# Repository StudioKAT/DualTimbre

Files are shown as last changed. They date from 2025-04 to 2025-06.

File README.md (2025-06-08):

# Dual Timbre
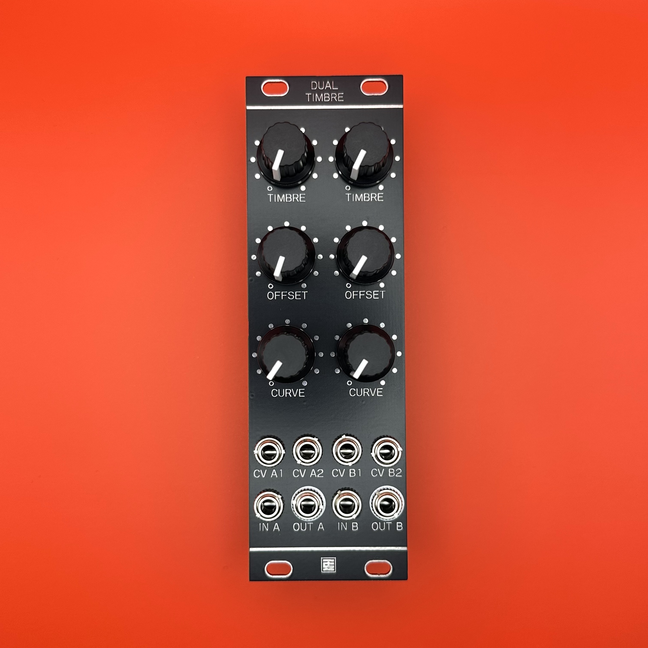
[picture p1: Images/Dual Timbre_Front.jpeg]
Dual Timbre Front


## 概要 / Overview

**Dual Timbre** は、Buchlaのウェーブフォルダー回路を現代的にアレンジした、デュアル構成のサウンドシェイピングツールです。  
VCAのレスポンスカーブは、リニアからエクスポネンシャルまで連続的に調整可能です。  
TIMBREおよびOFFSETノブは、パッチケーブルが接続されていない場合にはVCAの開き具合を調整するコントロールとして機能し、CV信号が接続されている場合にはアッテネーターとして動作します。  
CV入力は0～+10V、オーディオ入力は±5V（10Vpp）を想定しています。  

**Dual Timbre** is a dual-channel sound shaping tool that offers a modern take on the Buchla wavefolder circuit.  
The VCA response curve is continuously adjustable from linear to exponential.  
The TIMBRE and OFFSET knobs act as controls for the VCA's opening amount when no patch cable is connected, and serve as attenuators when a CV signal is present.  
The CV input expects a 0 to +10V signal, while the audio input is designed for ±5V (10V peak-to-peak).  

## 仕様 / Spec
- Format: Eurorack
- Function: Buchla Style Wave Folder
- Current needs: +12V: 55mA, -12V: 55mA
- Width: 8 HP
- Depth: 35mm (including power connector)

## 動画 / Movie
Dual Timbre (https://youtu.be/piGdNXMZIGw)

v1.1 UPDATE  
https://x.com/StudioKAT_synth/status/1931323608674316583

## 販売 / Sales

StudioKATオフィシャルショップで販売しています。(日本国内限定)  
 https://www.studiokat.jp/items/109037903

## ライセンス / License

この作品は [Creative Commons 表示 - 継承 4.0 国際 (CC BY-SA 4.0)](https://creativecommons.org/licenses/by-sa/4.0/deed.ja) の下でライセンスされています。  
This work is licensed under the [Creative Commons Attribution-ShareAlike 4.0 International License](https://creativecommons.org/licenses/by-sa/4.0/).

## クレジット / Credits

- Designed by : StudioKAT
- Website : https://www.studiokat.jp/
- GitHub : https://github.com/StudioKAT
- X(Twitter) : https://x.com/StudioKAT_synth
- Instagram : https://www.instagram.com/studiokat_modular/

## 更新履歴 / Changelog

- `2025-05-28` v1.0 Release
- `2025-06-08` v1.1 Curveの向き変更

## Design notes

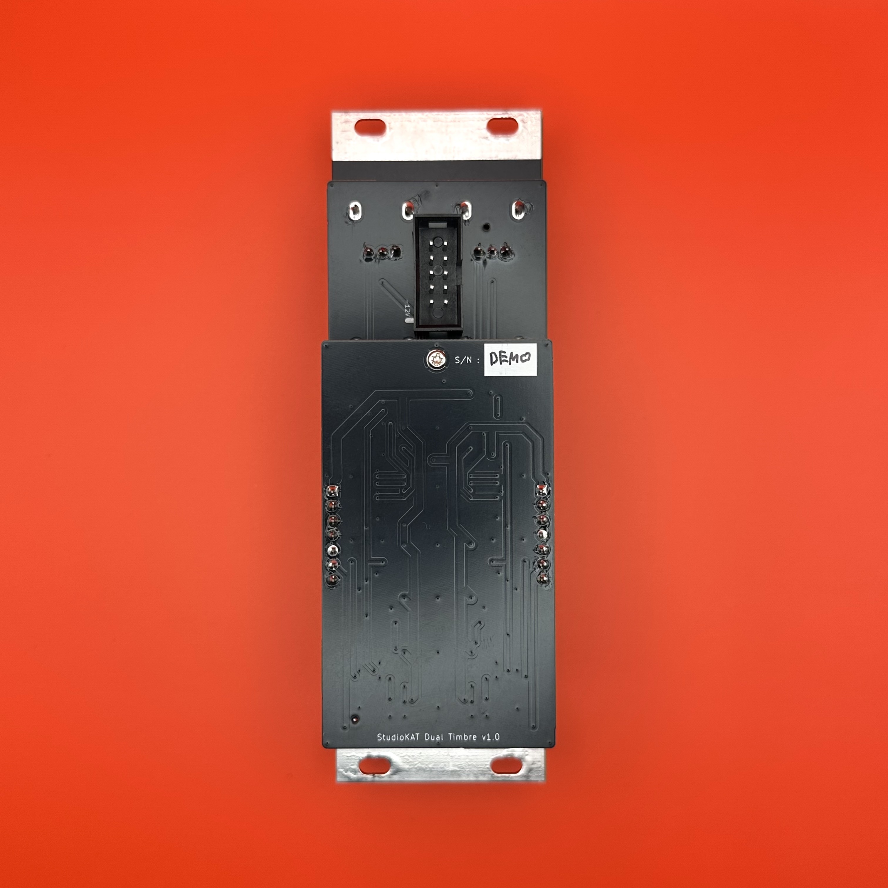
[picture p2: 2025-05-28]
Images/Dual Timbre_Back.jpeg

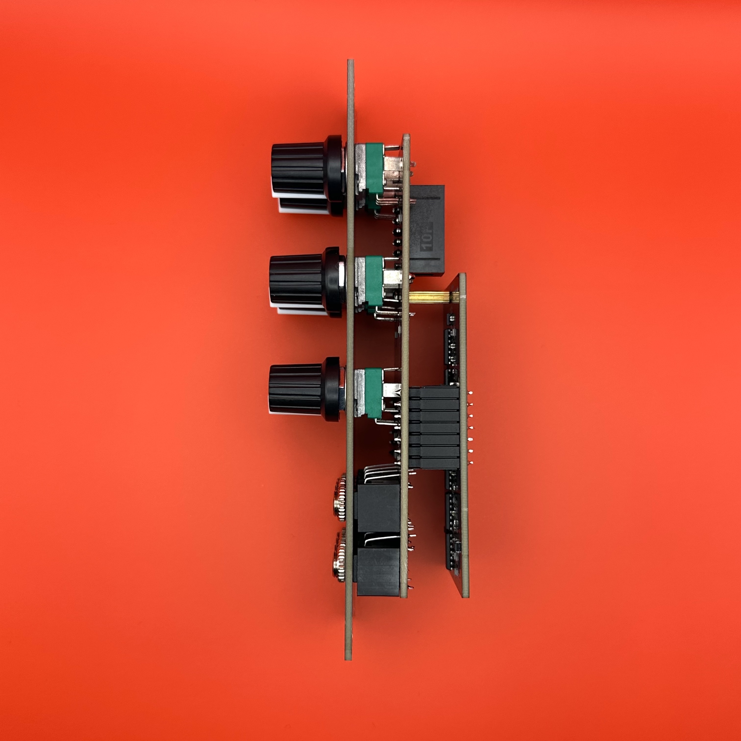
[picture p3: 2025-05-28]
Images/Dual Timbre_Side.jpeg

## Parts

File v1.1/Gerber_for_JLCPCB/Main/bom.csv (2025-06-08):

Designator | Footprint | Quantity | Value | LCSC Part #
C1, C2 | 0603 | 2 | 100nF | C14663
C10, C11, C12, C13, C14, C15, C16, C17, C18, C3, C6, C7, C8, C9 | 0402 | 14 | 100nF | C1525
C19, C20, C23, C24 | 0805 | 4 | 2.2nF | C28260
C21, C22, C25, C26 | 0402 | 4 | 100pF | C1546
C27, C28 | 0402 | 2 | 47pF | C1567
C4, C5 | 0805 | 2 | 22uF | C45783
D1, D2 | D_SOD-323 | 2 | 1N5819WS | C64886
D3, D4, D5, D6 | D_SOD-323 | 4 | 1N4148WS | C2128
J1 | BoxHeader_2x05_2.54mm_Europower | 1 | POWER
J10 | AudioJack_PJ301M-12 | 1 | Offset_CV_2
J11 | AudioJack_PJ301M-12 | 1 | Audio_IN_2
J12 | AudioJack_PJ301M-12 | 1 | TIMBRE_OUT_1
J13 | AudioJack_PJ301M-12 | 1 | TIMBRE_OUT_2
J2, J3 | PinSocket_1x07_P2.54mm_Vertical | 2 | Conn_01x07_Socket
J4, J5 | PinHeader_1x07_P2.54mm_Vertical | 2 | Conn_01x07_Pin
J6 | AudioJack_PJ301M-12 | 1 | Timbre_CV_1
J7 | AudioJack_PJ301M-12 | 1 | Offset_CV_1
J8 | AudioJack_PJ301M-12 | 1 | Audio_IN_1
J9 | AudioJack_PJ301M-12 | 1 | Timbre_CV_2
R1, R48, R72 | 0402 | 3 | 1K | C11702
R10, R21 | 0402 | 2 | 20K | C25765
R11, R19, R22, R8 | 0402 | 4 | 120R | C25079
R12, R23 | 0603 | 2 | 2K | C22975
R13, R24 | 0603 | 2 | 15K | C22809
R14, R16, R3, R5 | 0603 | 4 | 24K | C23352
R15, R17, R4, R6 | 0603 | 4 | 120K | C25808
R18, R7 | 0603 | 2 | 43K | C23172
R2 | 0402 | 1 | 510K | C11616
R20, R9 | 0402 | 2 | 10M | C26082
R25, R49 | 0402 | 2 | 10K | C25744
R26, R43, R45, R50, R67, R69 | 0402 | 6 | 51K | C25794
R27, R51 | 0603 | 2 | 91K | C23265
R28, R52 | 0603 | 2 | 30K | C22984
R29, R53 | 0402 | 2 | 68K | C36871
R30, R31, R32, R33, R34, R44, R54, R55, R56, R57, R58, R68 | 0402 | 12 | 150K | C25755
R35, R59 | 0402 | 2 | 100K | C25741
R36, R60 | 0402 | 2 | 47K | C25792
R37, R61 | 0402 | 2 | 470K | C25790
R38, R62 | 0402 | 2 | 18K | C25762
R39, R63 | 0402 | 2 | 75K | C25798
R40, R64 | 0603 | 2 | 1.5M | C4172
R41, R65 | 0402 | 2 | 33K | C25779
R42, R66 | 0603 | 2 | 240K | C4197
R46, R70 | 0603 | 2 | 22K | C31850
R47, R71 | 0603 | 2 | 470K | C23178
RV1, RV2, RV3, RV4, RV5, RV6 | Potentiometer_RV09 | 6 | B10K
U1 | SOT-23 | 1 | CJ431 | C3113
U2, U3, U4, U5, U6 | SOIC-14_3.9x8.7mm_P1.27mm | 5 | TL074 | C6963
U7 | SOIC-16_3.9x9.9mm_P1.27mm | 1 | SSI2164

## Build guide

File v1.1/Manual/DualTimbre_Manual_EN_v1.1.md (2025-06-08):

# Dual Timbre Manual (EN)

Dual Timbre Front

## Overview

**Dual Timbre** is a dual-channel sound shaping tool that offers a modern take on the Buchla wavefolder circuit.  
The VCA response curve is continuously adjustable from linear to exponential.  
The TIMBRE and OFFSET knobs act as controls for the VCA’s opening amount when no patch cable is connected, and serve as attenuators when a CV signal is connected.  
The CV inputs are designed for 0 to +10V signals, and the audio inputs for ±5V (10V peak-to-peak).

---

## Specifications

- **Format**: Eurorack  
- **Width**: 8 HP  
- **Depth**: 35 mm  
- **Current Consumption**: +12V: 55mA / -12V: 55mA  

> **IMPORTANT**: Connect the ribbon cable so that the red stripe aligns with -12V.  
> Incorrect connection may damage the module.  
> **Always check cable orientation before powering on.**

---

## Functions of Each Section

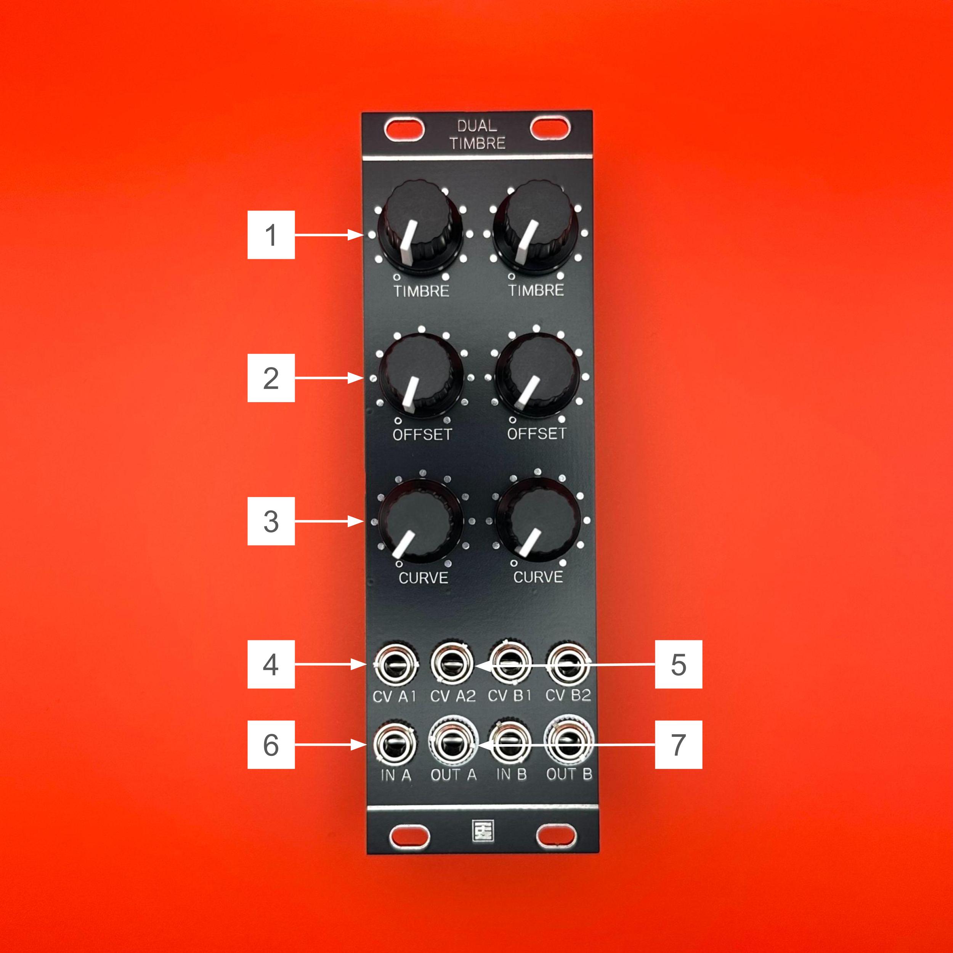
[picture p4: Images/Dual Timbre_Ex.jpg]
explanation


1. **TIMBRE**  
   Knob for adjusting the wavefolding amount.  
   Turning left sets it to minimum, turning right to maximum.  
   Also functions as an attenuator for the signal connected to CV A1.

2. **OFFSET**  
   Knob for adding an offset voltage to TIMBRE.  
   Turning left sets it to minimum, turning right to maximum.  
   Also functions as an attenuator for the signal connected to CV A2.  

3. **CURVE**  
   Knob for adjusting the VCA response curve.  
   Continuously variable from linear to exponential.

4. **CV A1**  
   CV input for TIMBRE.  
   Designed for 0 to +10V signals.

5. **CV A2**  
   CV input for OFFSET.  
   Designed for 0 to +10V signals.

6. **IN A**  
   Audio input jack.  
   Designed for ±5V signals.

7. **OUT A**  
   Audio output jack.

---

> The left and right channels (A/B) share identical specifications.

---

## License

This work is licensed under the [Creative Commons Attribution-ShareAlike 4.0 International (CC BY-SA 4.0)](https://creativecommons.org/licenses/by-sa/4.0/deed.en).

---

## Credits

- **Designed by**: StudioKAT  
- **Website**: [https://www.studiokat.jp/](https://www.studiokat.jp/)  
- **GitHub**: [https://github.com/StudioKAT](https://github.com/StudioKAT)  
- **X (formerly Twitter)**: [https://x.com/StudioKAT_synth](https://x.com/StudioKAT_synth)  
- **Instagram**: [https://www.instagram.com/studiokat_modular/](https://www.instagram.com/studiokat_modular/)

---

## Revision History

- `2025-05-28`: v1.0 Release
- `2025-06-08`: v1.1 Curve direction changed.

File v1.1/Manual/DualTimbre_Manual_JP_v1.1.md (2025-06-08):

# Dual Timbre マニュアル（日本語）

Dual Timbre Front

## 概要

**Dual Timbre** は、Buchlaのウェーブフォルダー回路を現代的にアレンジした、デュアル構成のサウンドシェイピングツールです。  
VCAのレスポンスカーブは、リニアからエクスポネンシャルまで連続的に調整可能です。  
TIMBREおよびOFFSETノブは、パッチケーブルが接続されていない場合にはVCAの開き具合を調整するコントロールとして機能し、CV信号が接続されている場合にはアッテネーターとして動作します。  
CV入力は0～+10V、オーディオ入力は±5V（10Vpp）を想定しています。  

---

## 仕様

- **フォーマット**：Eurorack  
- **幅**：8 HP  
- **奥行き**：35 mm  
- **消費電流**：+12V: 55mA / -12V: 55mA  

> ※ ケーブルの赤いラインが -12V に接続されるようにしてください。  
> 誤って接続すると、モジュールが故障する可能性があります。  
> **電源投入前にケーブルの向きを必ず確認してください。**

---

## 各部の機能

explanation

1. **TIMBRE**  
   波形の折りたたみ量を調整するノブです。  
   左に回すと最小、右に回すと最大になります。  
   CV A1 に接続された信号のアッテネーターとしても動作します。

2. **OFFSET**  
   TIMBRE に加算するオフセット電圧を調整するノブです。  
   左に回すと最小、右に回すと最大になります。  
   CV A2 に接続された信号のアッテネーターとしても動作します。  

3. **CURVE**  
   VCA のレスポンスカーブを調整するノブです。  
   リニアからエクスポネンシャルまで連続的に調整可能です。

4. **CV A1**  
   TIMBREへのCV入力端子です。  
   0~+10Vの入力を想定しています。

5. **CV A2**  
   OFFSETへのCV入力端子です。
   0~+10Vの入力を想定しています。

6. **IN A**  
   オーディオ信号の入力端子です。
   ±5Vの入力を想定しています。  

7. **OUT A**  
   オーディオ信号の出力端子です。

---

> 左右チャンネル（A/B）は同一仕様です。  

---

## ライセンス

この作品は [Creative Commons 表示 - 継承 4.0 国際 (CC BY-SA 4.0)](https://creativecommons.org/licenses/by-sa/4.0/deed.ja) の下でライセンスされています。

---

## クレジット

- **Designed by**：StudioKAT  
- **Website**：[https://www.studiokat.jp/](https://www.studiokat.jp/)  
- **GitHub**：[https://github.com/StudioKAT](https://github.com/StudioKAT)  
- **X（旧Twitter）**：[https://x.com/StudioKAT_synth](https://x.com/StudioKAT_synth)  
- **Instagram**：[https://www.instagram.com/studiokat_modular/](https://www.instagram.com/studiokat_modular/)

---

## 更新履歴

- `2025-05-28`：v1.0 リリース  
- `2025-06-08`：v1.1 Curveの向き変更

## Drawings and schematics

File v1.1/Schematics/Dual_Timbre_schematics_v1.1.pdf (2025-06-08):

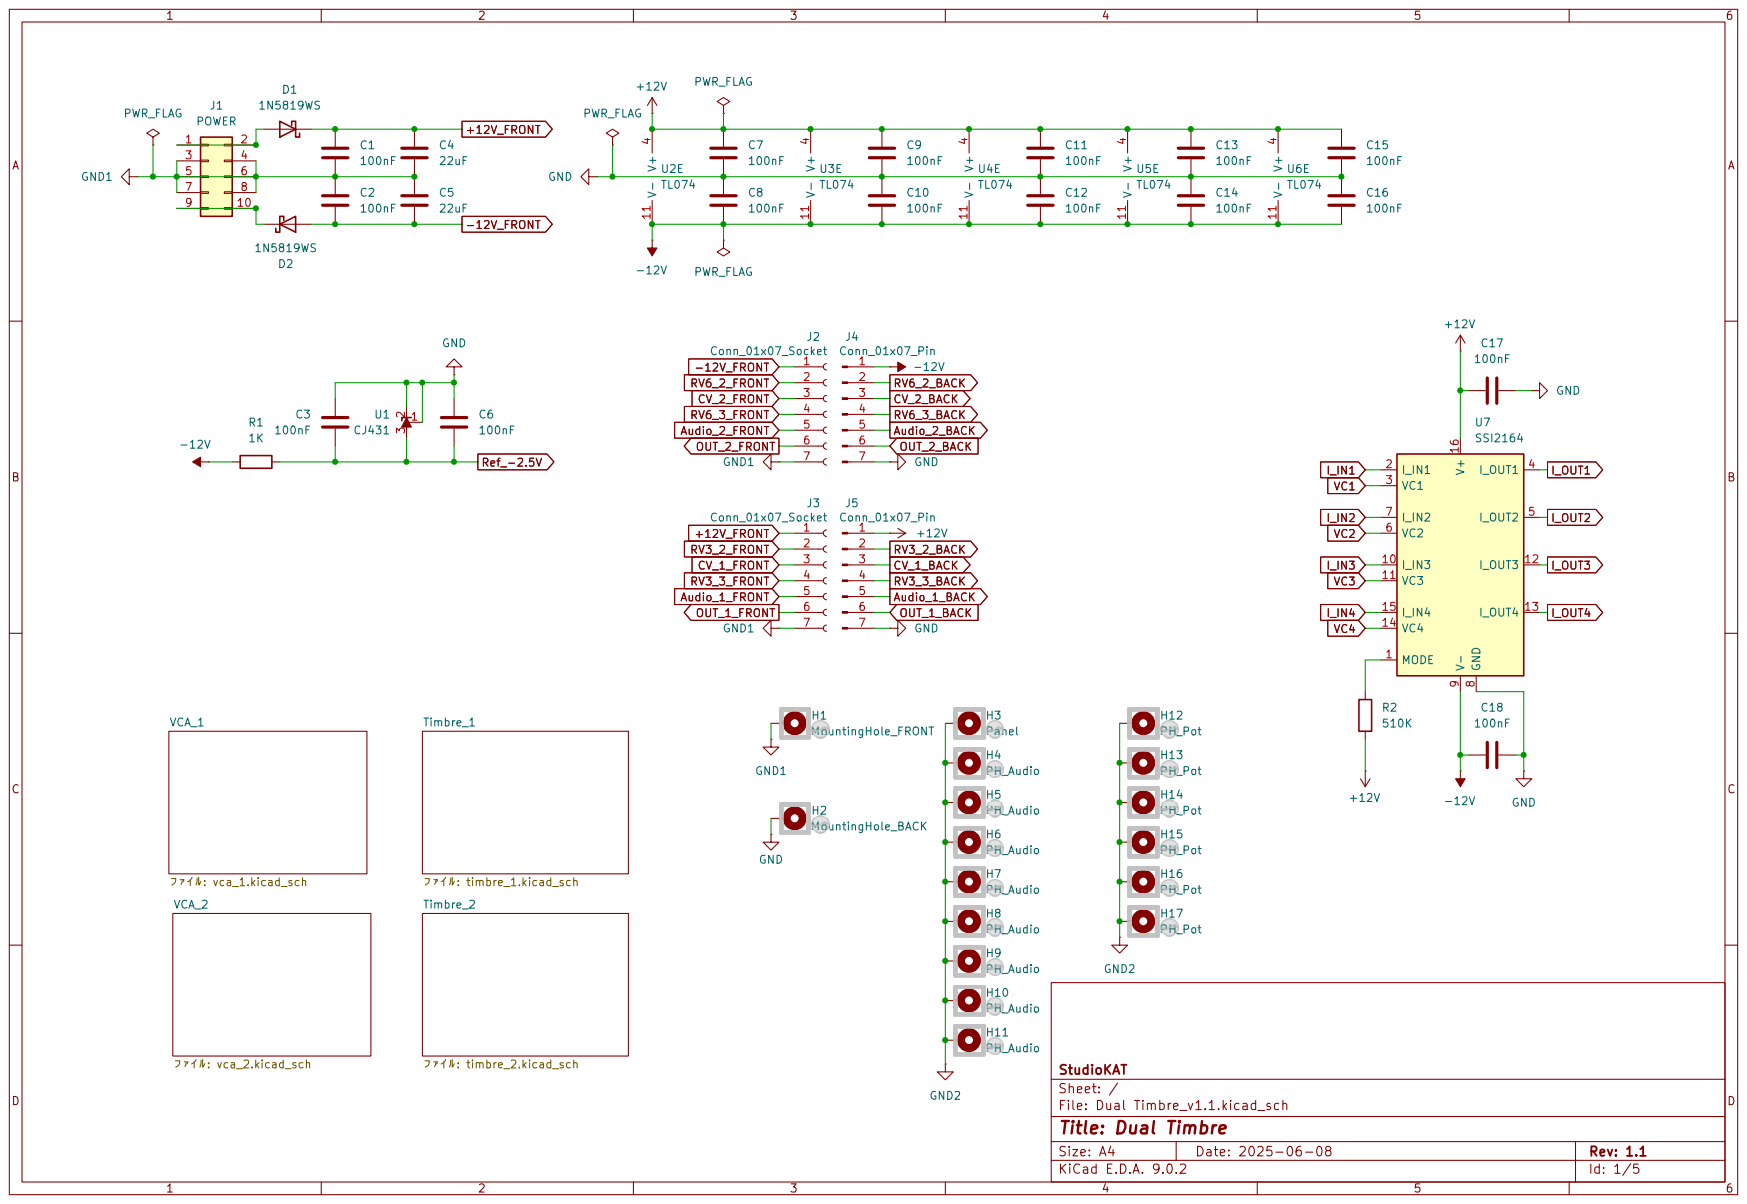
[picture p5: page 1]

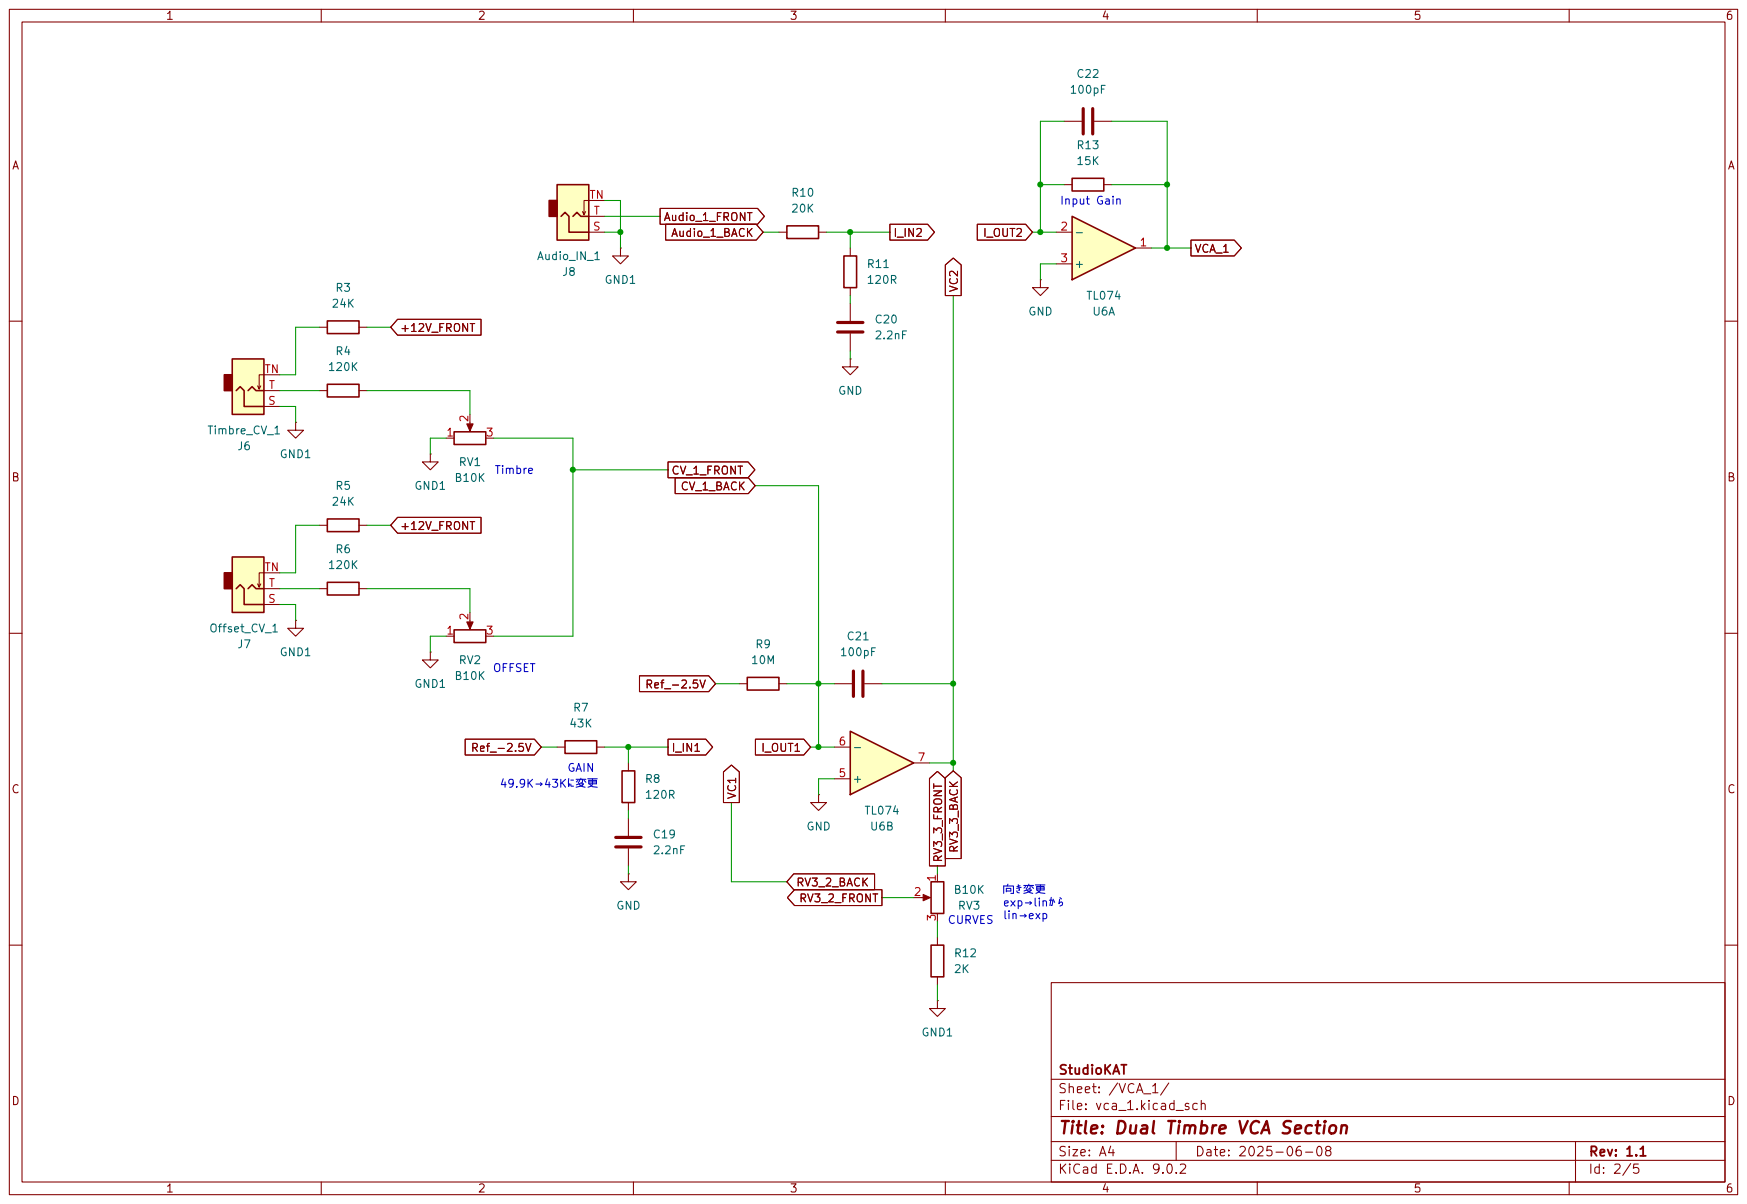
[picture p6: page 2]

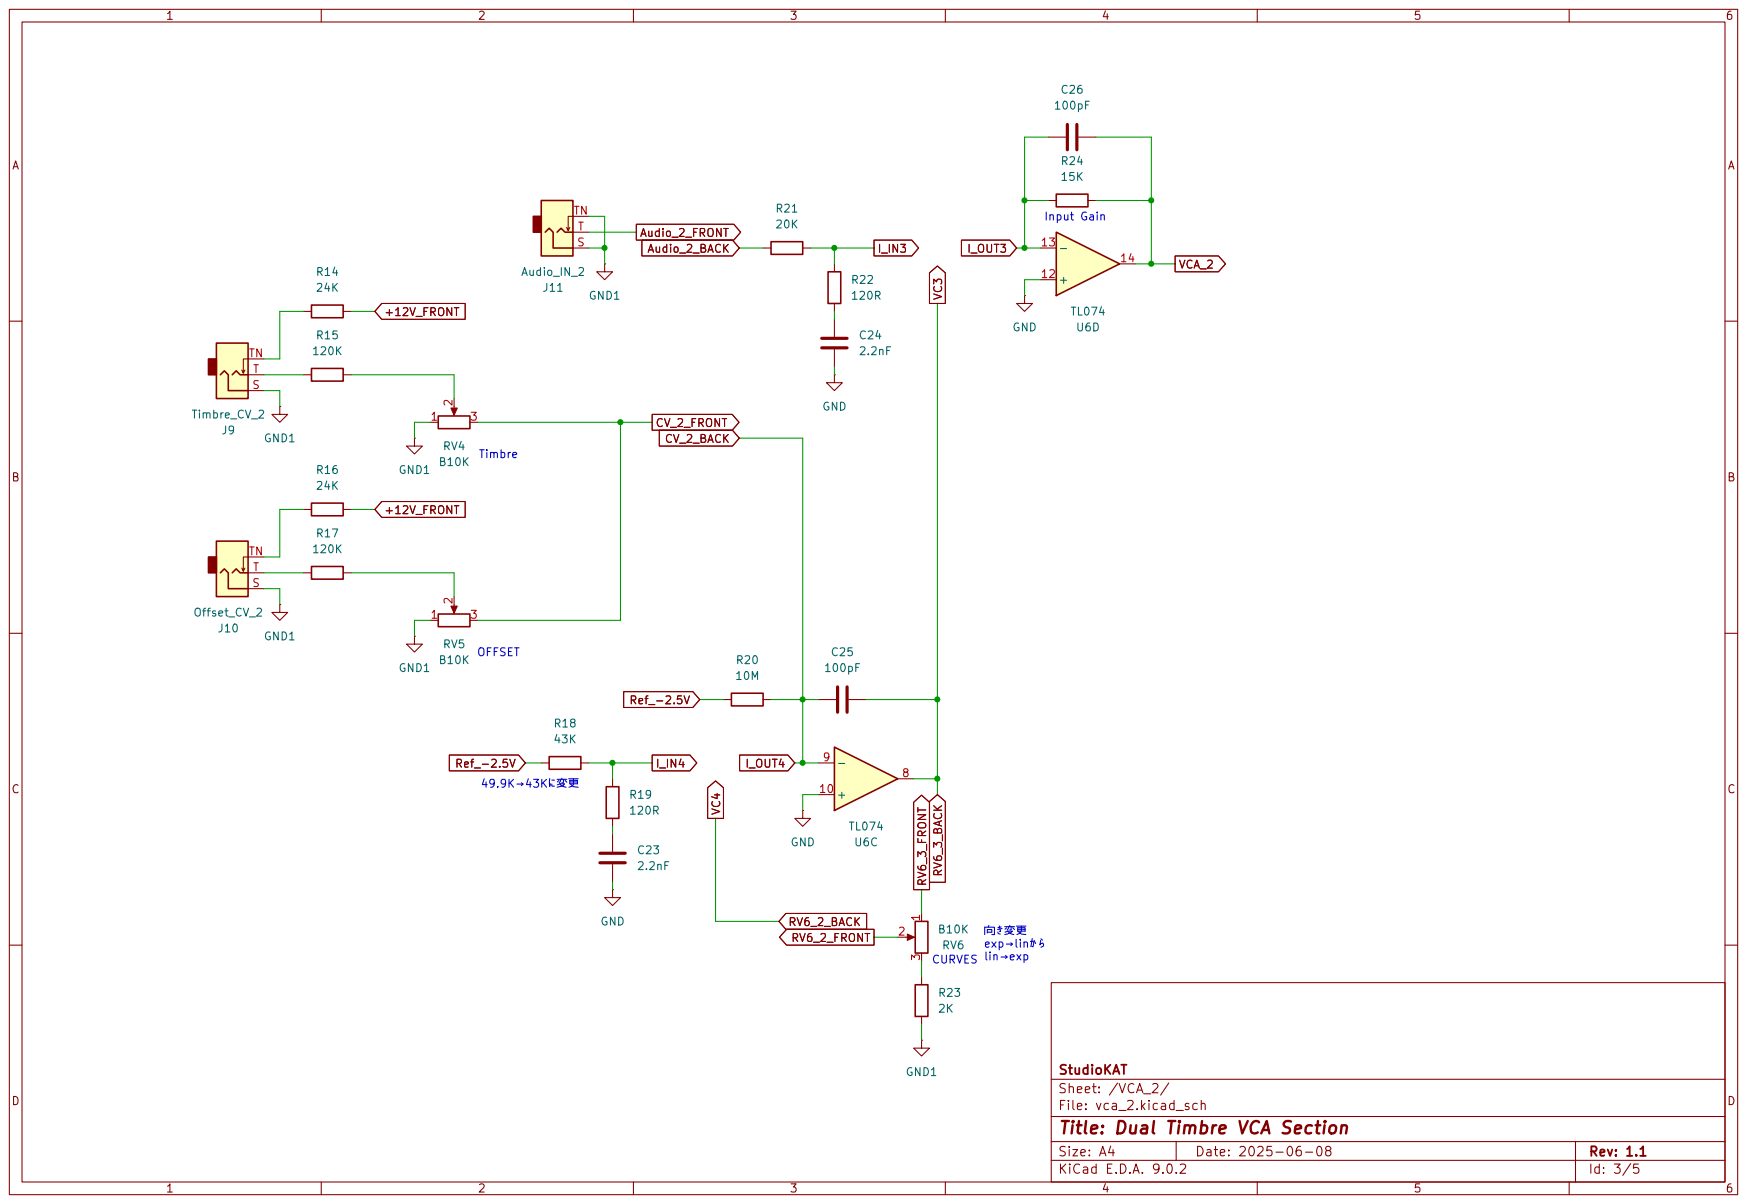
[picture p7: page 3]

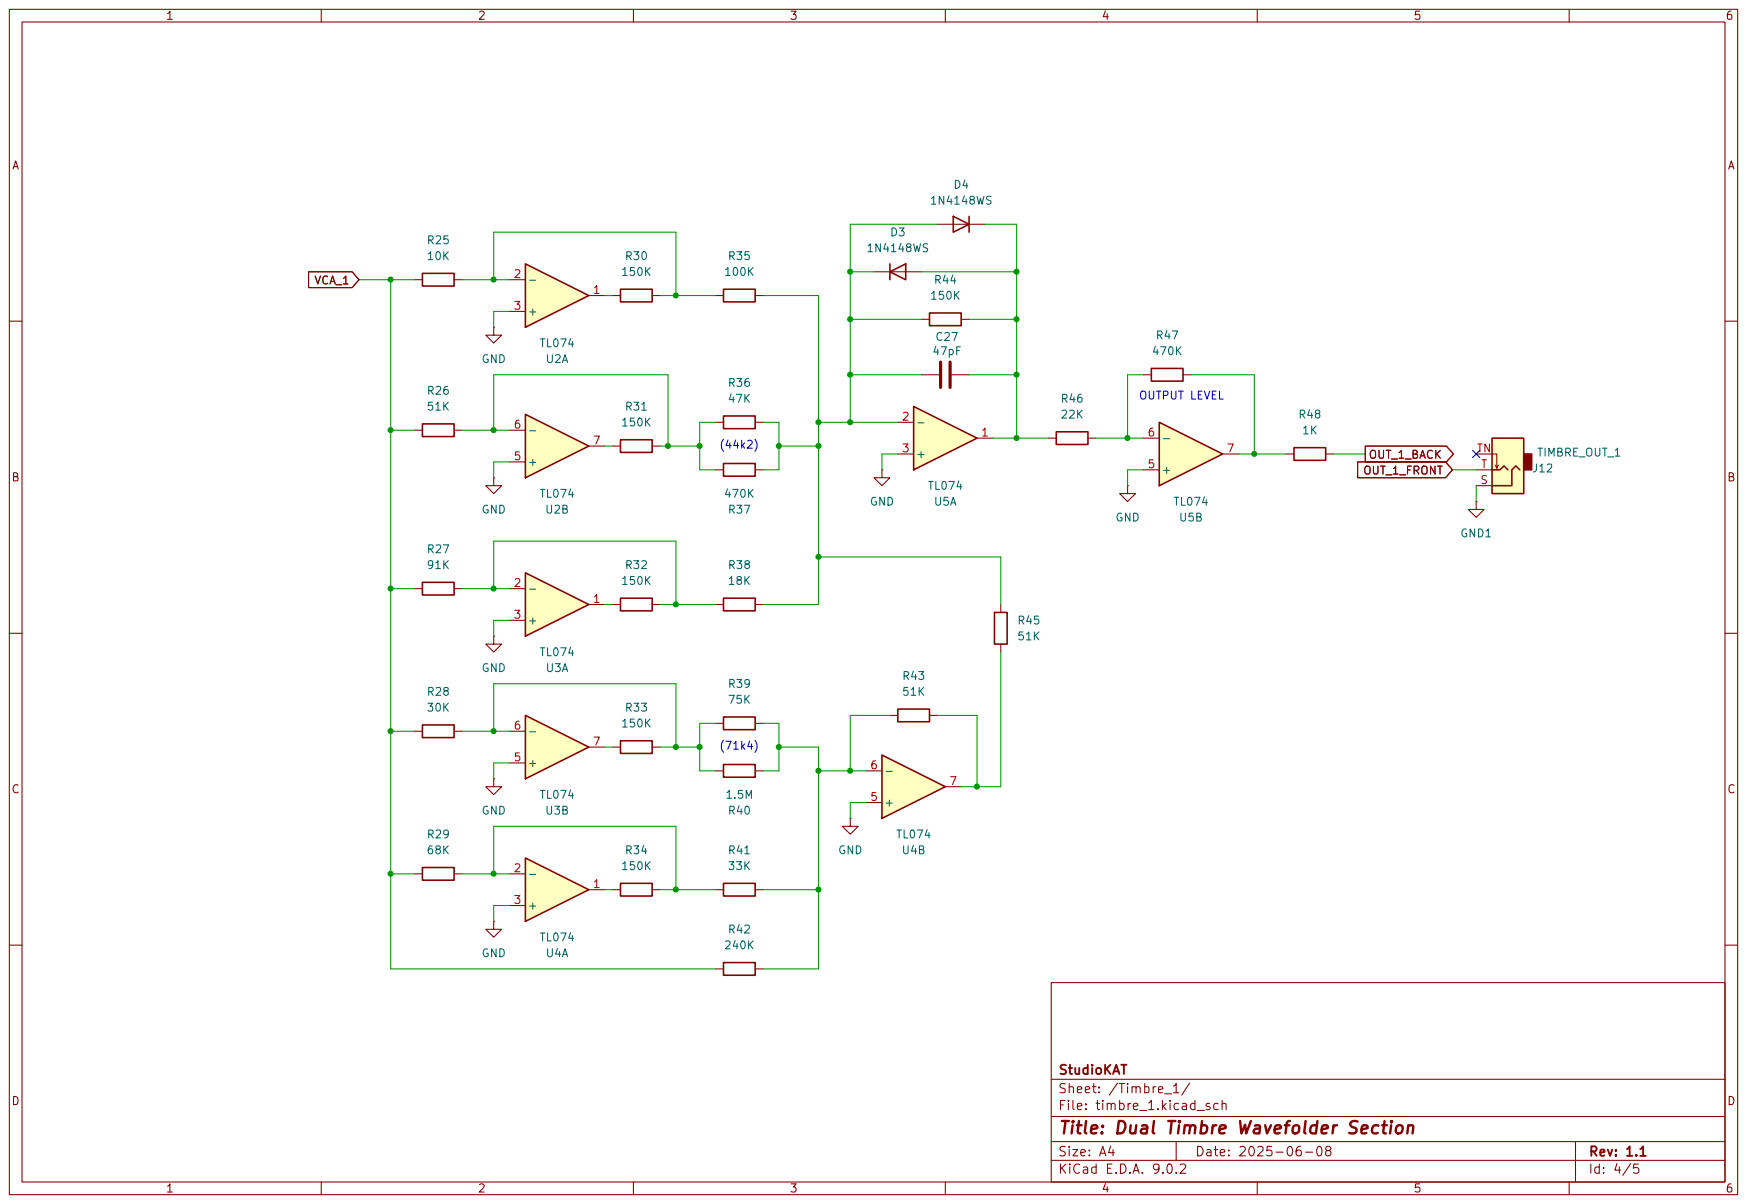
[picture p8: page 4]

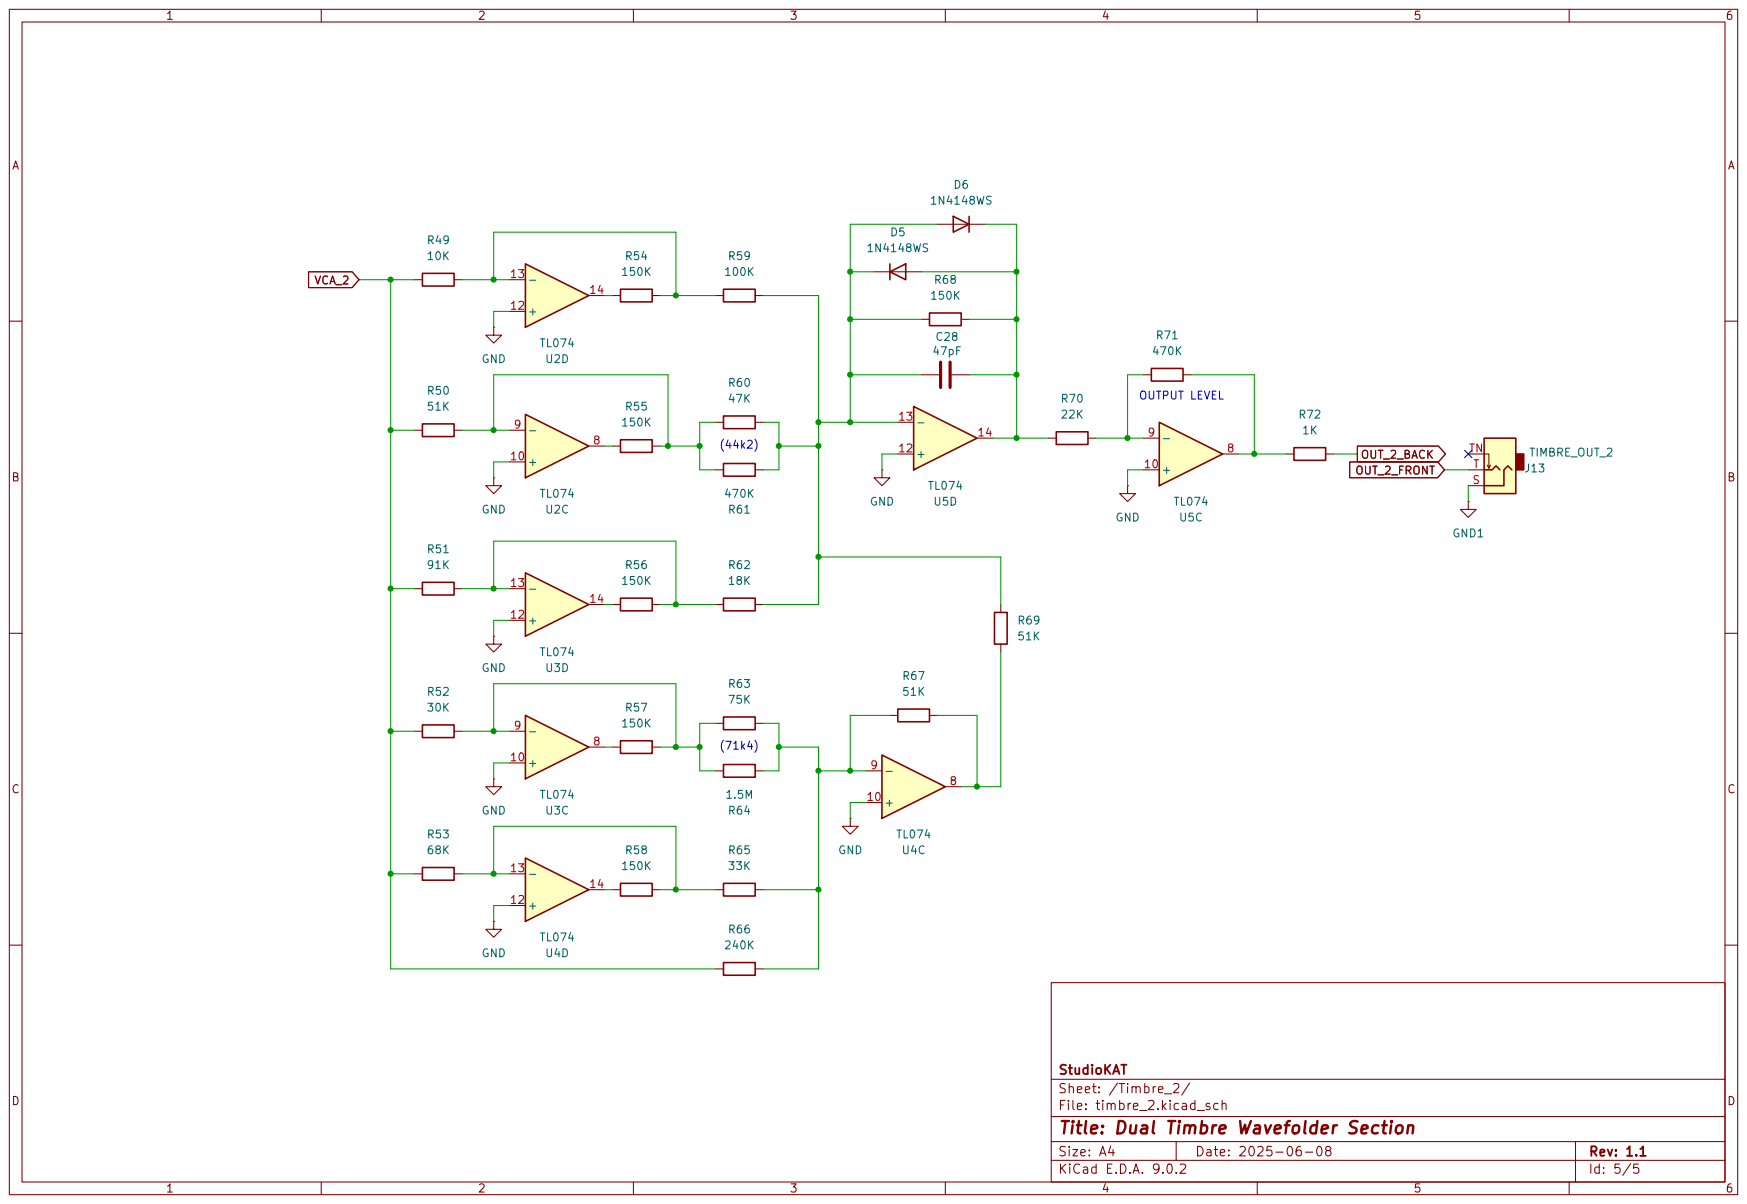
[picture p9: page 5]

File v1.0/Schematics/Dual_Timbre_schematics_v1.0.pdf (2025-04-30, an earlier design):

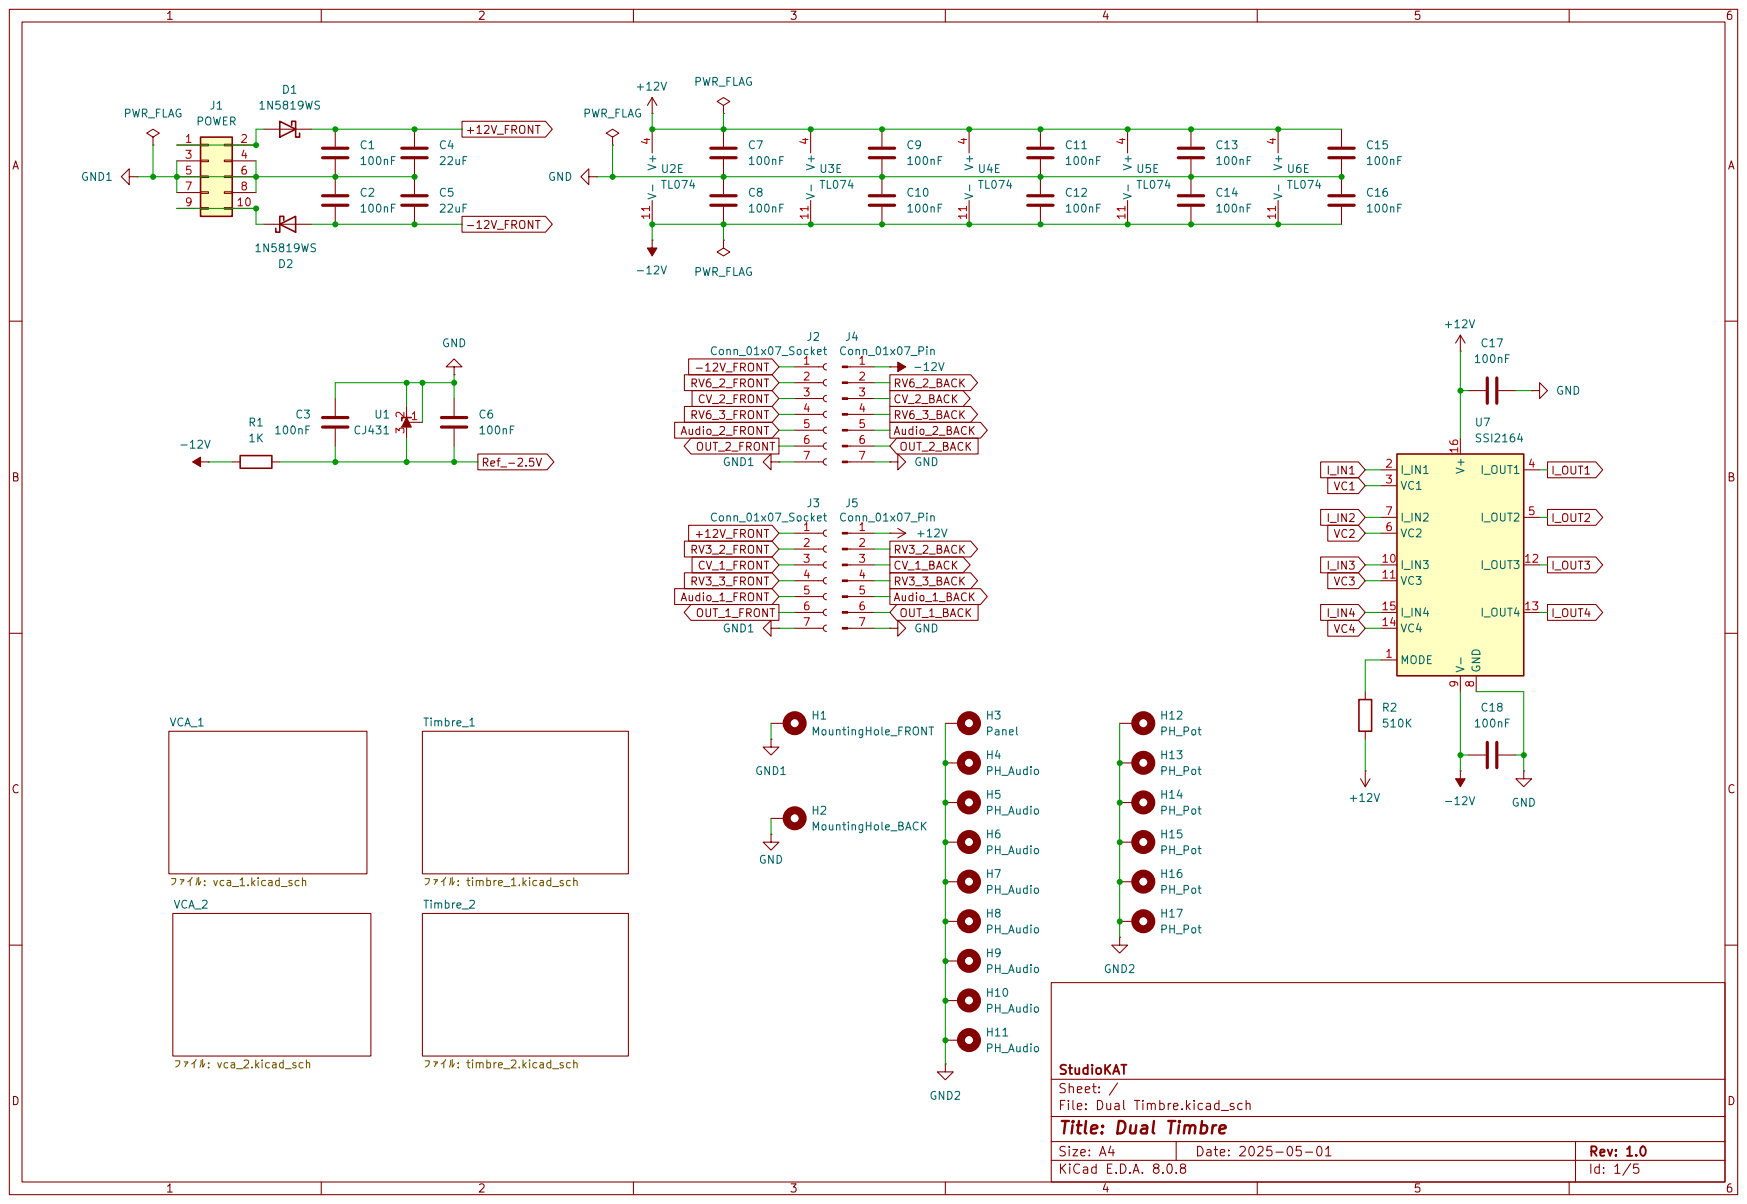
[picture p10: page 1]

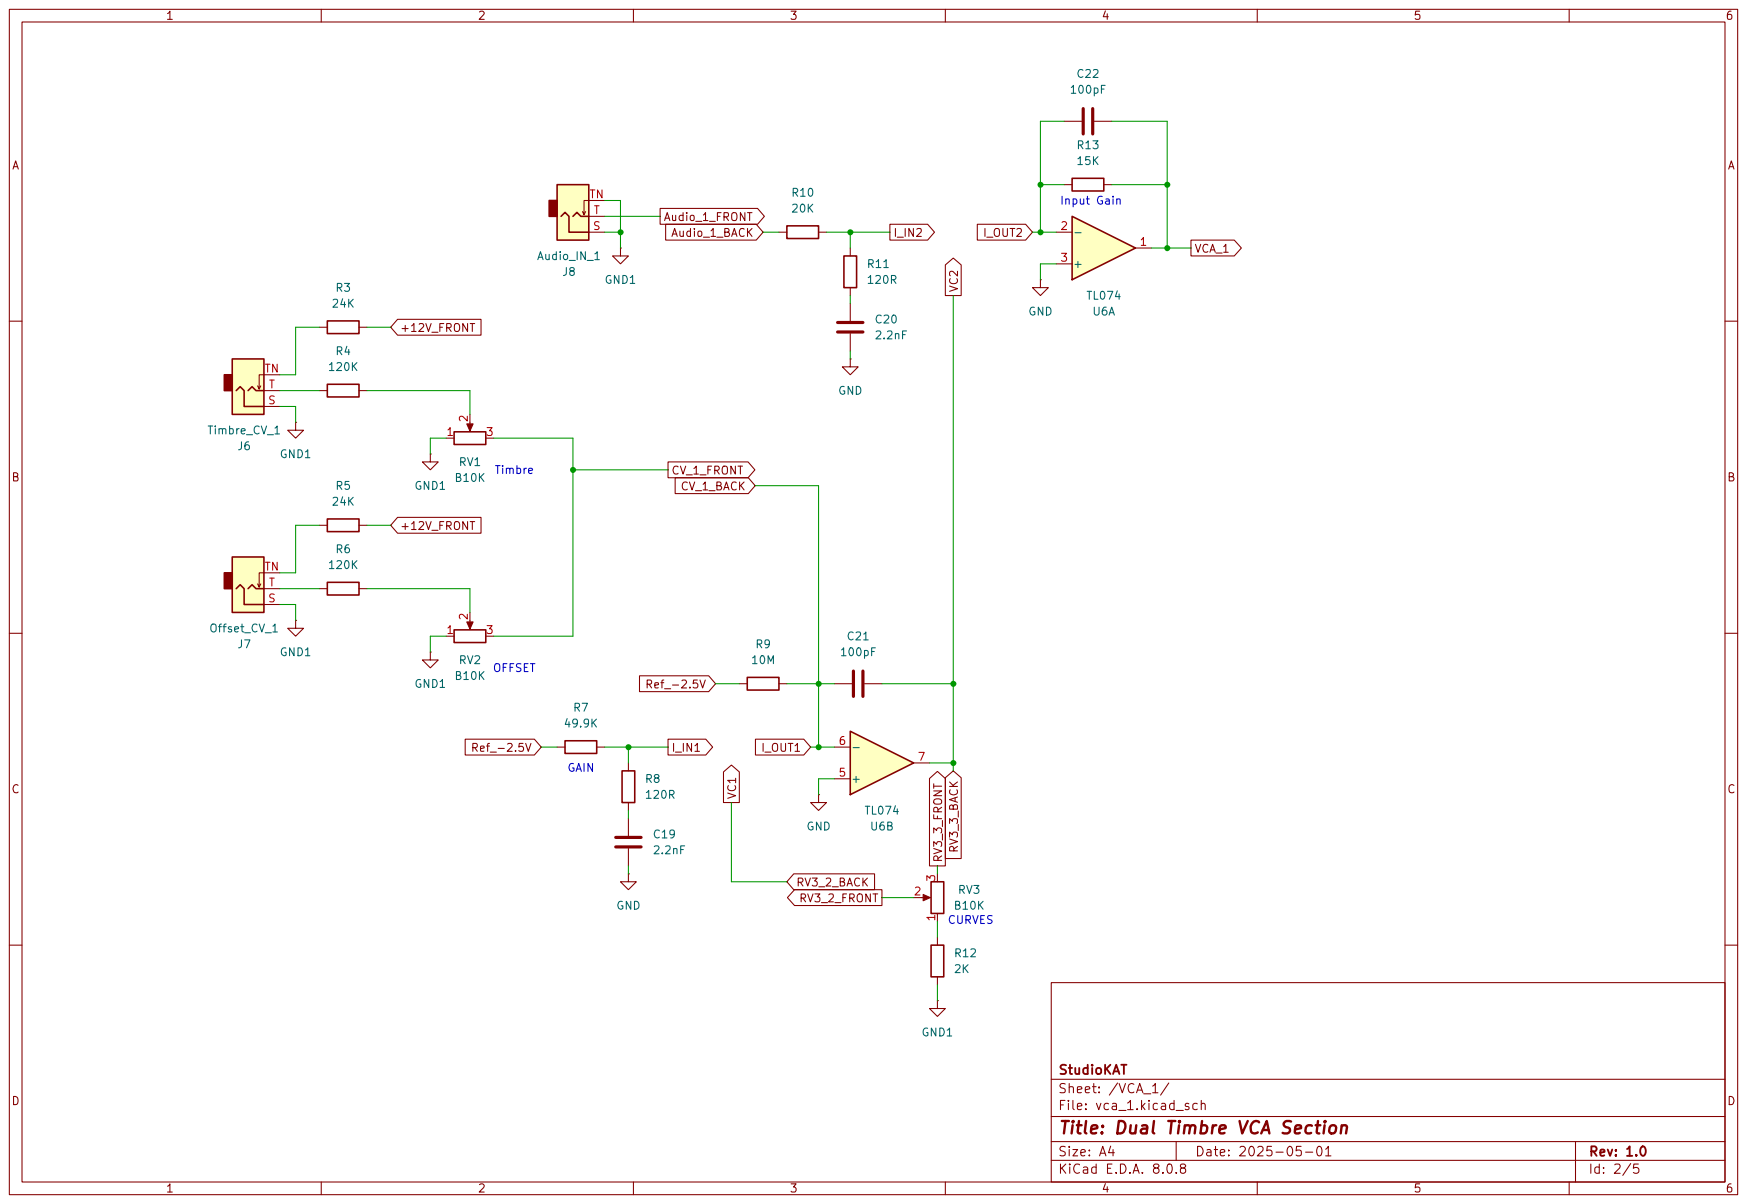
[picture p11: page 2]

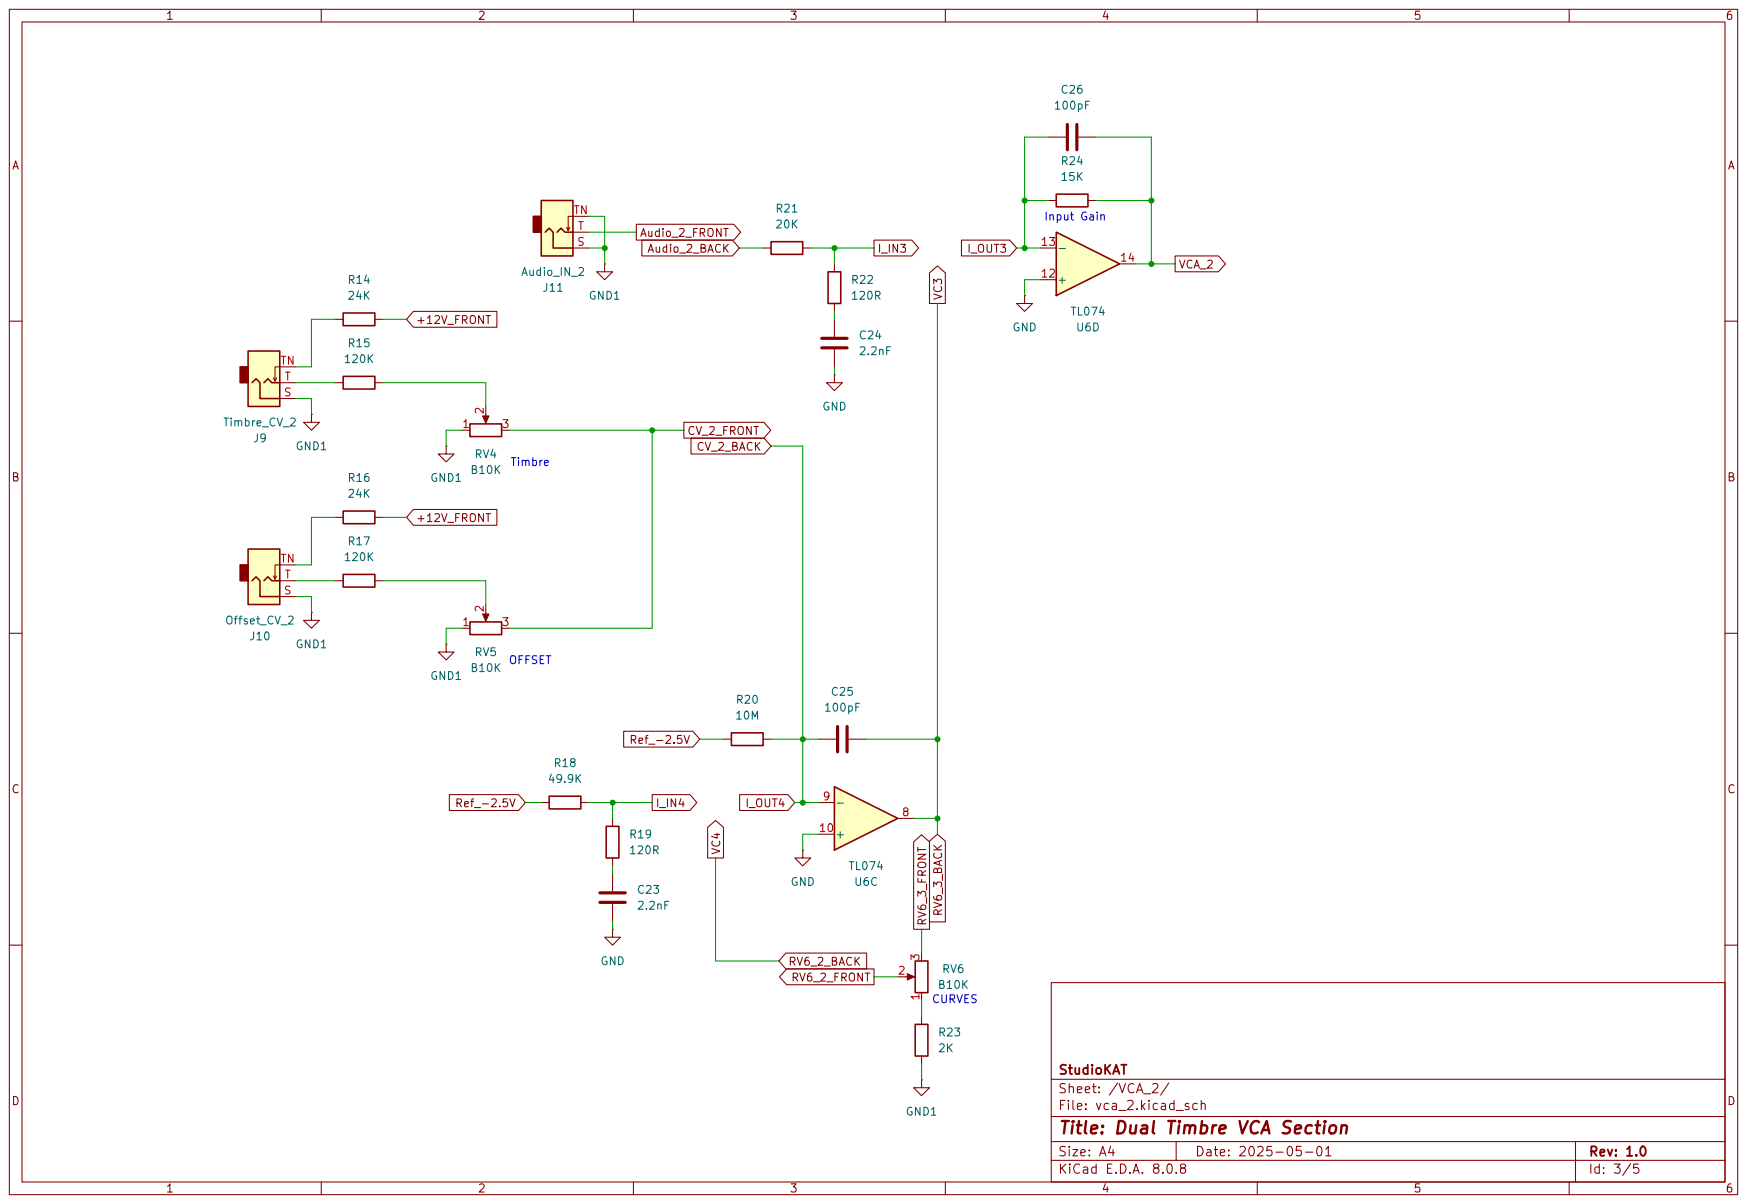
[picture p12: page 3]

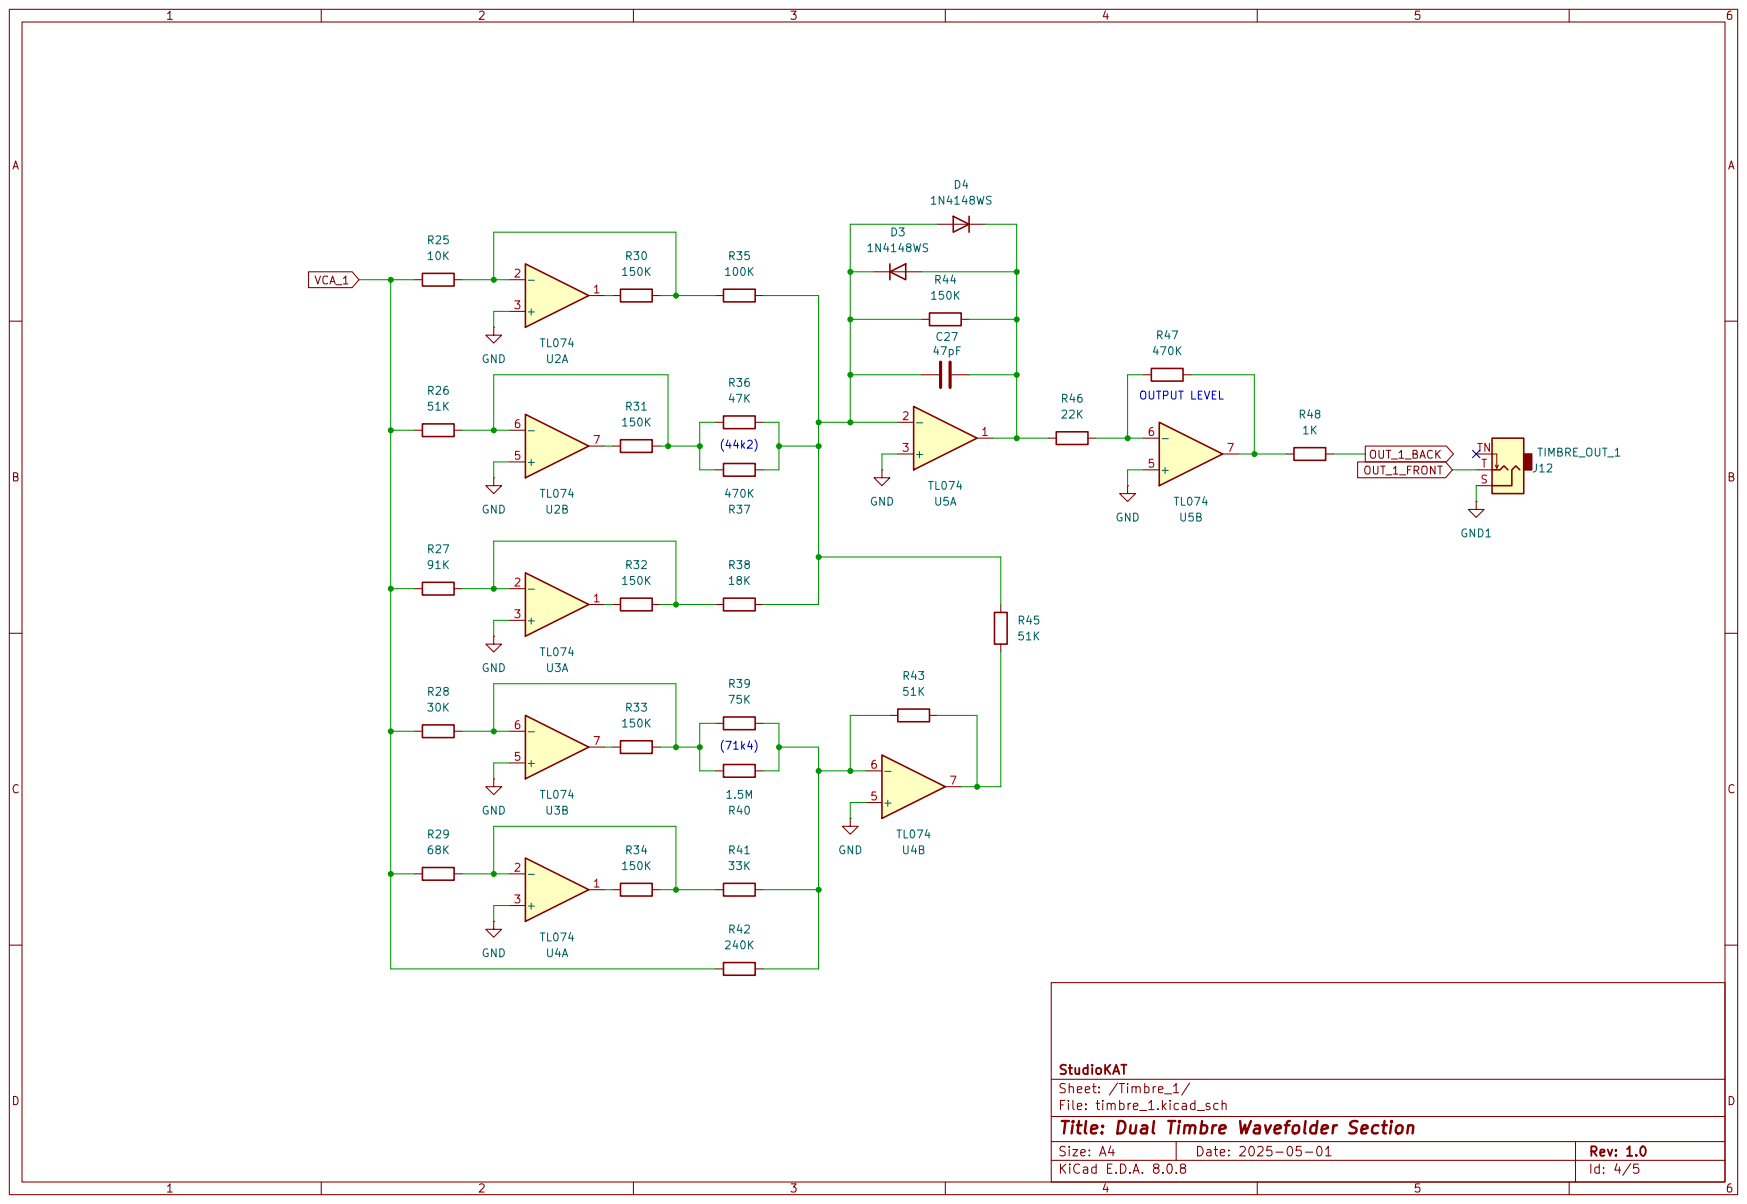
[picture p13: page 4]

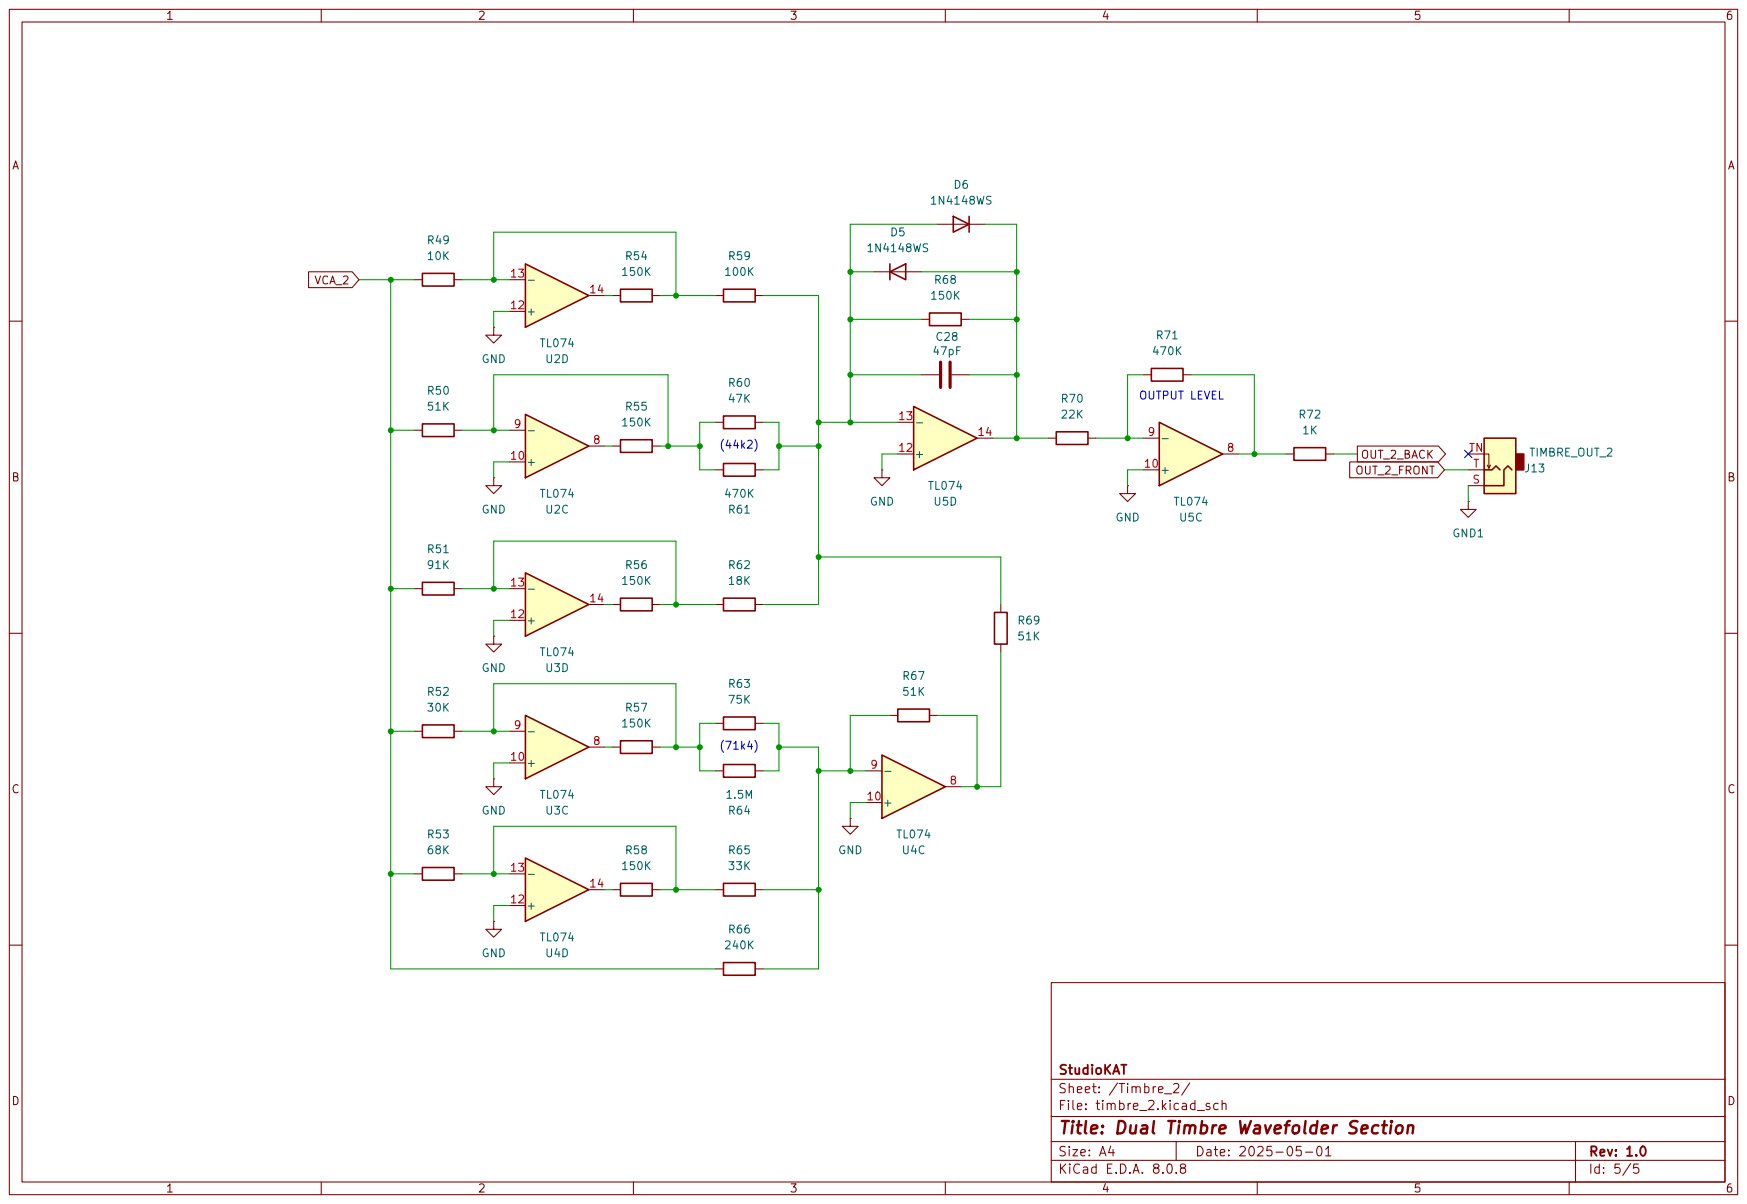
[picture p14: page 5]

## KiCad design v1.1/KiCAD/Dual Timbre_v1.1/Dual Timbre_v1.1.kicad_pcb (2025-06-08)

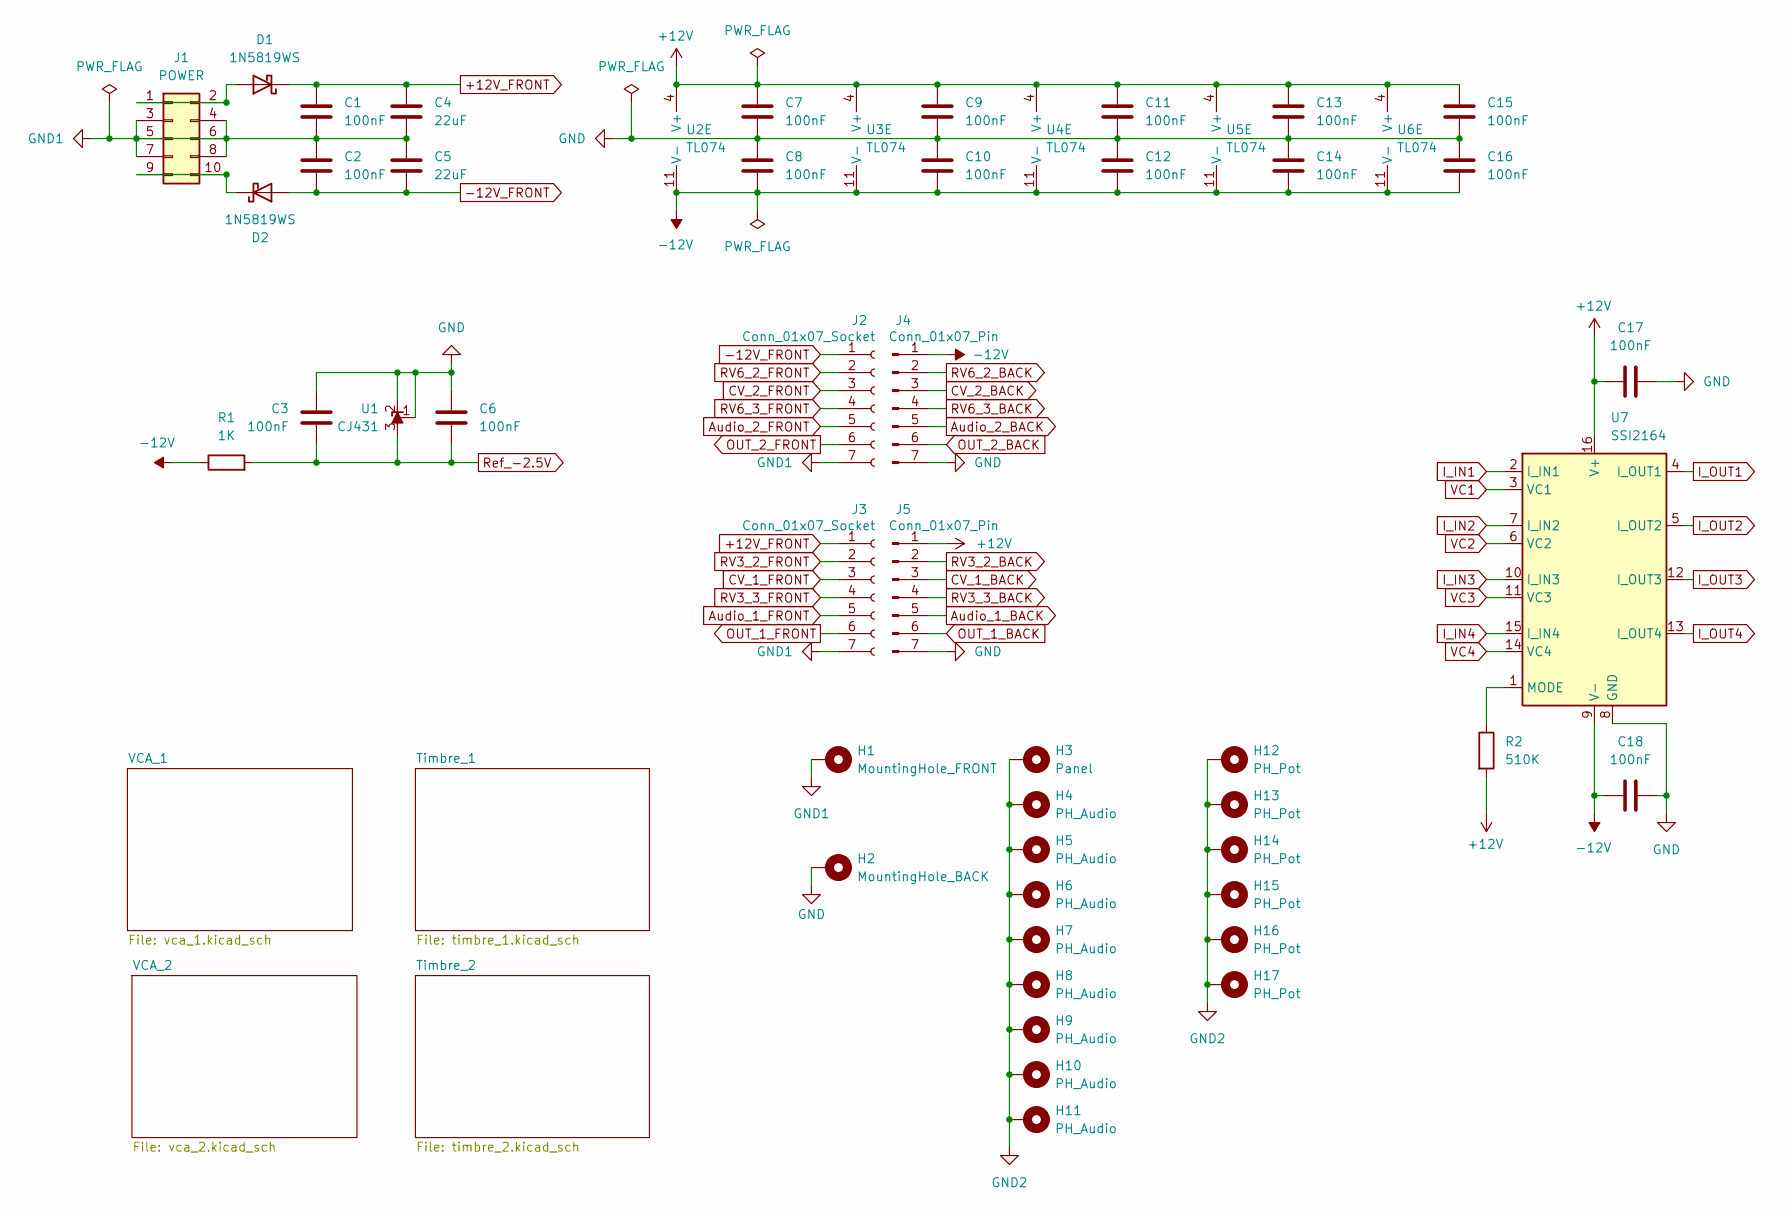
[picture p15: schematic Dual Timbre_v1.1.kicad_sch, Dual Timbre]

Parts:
C1, C2: 100nF; C_0603_1608Metric; LCSC C14663
C3, C6, C7, C8, C9, C10, C11, C12, C13, C14, C15, C16, C17, C18: 100nF; C_0402_1005Metric; LCSC C1525
C4, C5: 22uF; C_0805_2012Metric; LCSC C45783
D1, D2: 1N5819WS; D_SOD-323; LCSC C64886
H1: MountingHole_FRONT; MountingHole_2.2mm_M2_ISO7380_Pad
H2: MountingHole_BACK; MountingHole_2.2mm_M2_ISO7380_Pad
H3: Panel; Panel_8HP
H4, H5, H6, H7, H8, H9, H10, H11: PH_Audio; PH_AudioJack_3.5mm_Pad
H12, H13, H14, H15, H16, H17: PH_Pot; PH_RK097_15mmKnob_Pad
J1: POWER; BoxHeader_2x05_2.54mm_Europower
J2, J3: Conn_01x07_Socket; PinSocket_1x07_P2.54mm_Vertical
J4, J5: Conn_01x07_Pin; PinHeader_1x07_P2.54mm_Vertical
R1: 1K; R_0402_1005Metric; LCSC C11702
R2: 510K; R_0402_1005Metric; LCSC C11616
U1: CJ431; SOT-23; LCSC C3113
U2, U3, U4, U5, U6: TL074; SOIC-14_3.9x8.7mm_P1.27mm; LCSC C6963
U7: SSI2164; SOIC-16_3.9x9.9mm_P1.27mm

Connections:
+12V: C7.1, C9.1, C11.1, C13.1, C15.1, C17.1, J5.1, R2.2, U2.4 (V+), U3.4 (V+), U4.4 (V+), U5.4 (V+), U6.4 (V+), U7.16 (V+)
+12V_FRONT: C1.1, C4.1, D1.1 (K), J3.1; also elsewhere on the board
-12V: C8.2, C10.2, C12.2, C14.2, C16.2, C18.1, J4.1, R1.1, U2.11 (V-), U3.11 (V-), U4.11 (V-), U5.11 (V-), U6.11 (V-), U7.9 (V-)
-12V_FRONT: C2.2, C5.2, D2.2 (A), J2.1
Audio_1_BACK: J5.5; also elsewhere on the board
Audio_1_FRONT: J3.5; also elsewhere on the board
Audio_2_BACK: J4.5; also elsewhere on the board
Audio_2_FRONT: J2.5; also elsewhere on the board
CV_1_BACK: J5.3, U7.4 (I_OUT1); also elsewhere on the board
CV_1_FRONT: J3.3; also elsewhere on the board
CV_2_BACK: J4.3, U7.13 (I_OUT4); also elsewhere on the board
CV_2_FRONT: J2.3; also elsewhere on the board
GND: C3.1, C6.1, C7.2, C8.1, C9.2, C10.1, C11.2, C12.1, C13.2, C14.1, C15.2, C16.1, C17.2, C18.2, H2.1, J4.7, J5.7, U1.1 (REF), U1.2 (K), U7.8 (GND); also elsewhere on the board
GND1: C1.2, C2.1, C4.2, C5.1, H1.1, J1.3, J1.4, J1.5, J1.6, J1.7, J1.8, J2.7, J3.7; also elsewhere on the board
GND2: H3.1, H4.1, H5.1, H6.1, H7.1, H8.1, H9.1, H10.1, H11.1, H12.1, H13.1, H14.1, H15.1, H16.1, H17.1
I_IN1: U7.2 (I_IN1); also elsewhere on the board
I_IN2: U7.7 (I_IN2); also elsewhere on the board
I_IN3: U7.10 (I_IN3); also elsewhere on the board
I_IN4: U7.15 (I_IN4); also elsewhere on the board
I_OUT2: U7.5 (I_OUT2); also elsewhere on the board
I_OUT3: U7.12 (I_OUT3); also elsewhere on the board
unnamed: D1.2 (A), J1.1, J1.2
unnamed: D2.1 (K), J1.9, J1.10
unnamed: R2.1, U7.1 (MODE)
OUT_1_BACK: J5.6; also elsewhere on the board
OUT_1_FRONT: J3.6; also elsewhere on the board
OUT_2_BACK: J4.6; also elsewhere on the board
OUT_2_FRONT: J2.6; also elsewhere on the board
RV3_2_FRONT: J3.2; also elsewhere on the board
RV3_3_BACK: J5.4, U7.6 (VC2); also elsewhere on the board
RV3_3_FRONT: J3.4; also elsewhere on the board
RV6_2_FRONT: J2.2; also elsewhere on the board
RV6_3_BACK: J4.4, U7.11 (VC3); also elsewhere on the board
RV6_3_FRONT: J2.4; also elsewhere on the board
Ref_-2.5V: C3.2, C6.2, R1.2, U1.3 (A); also elsewhere on the board

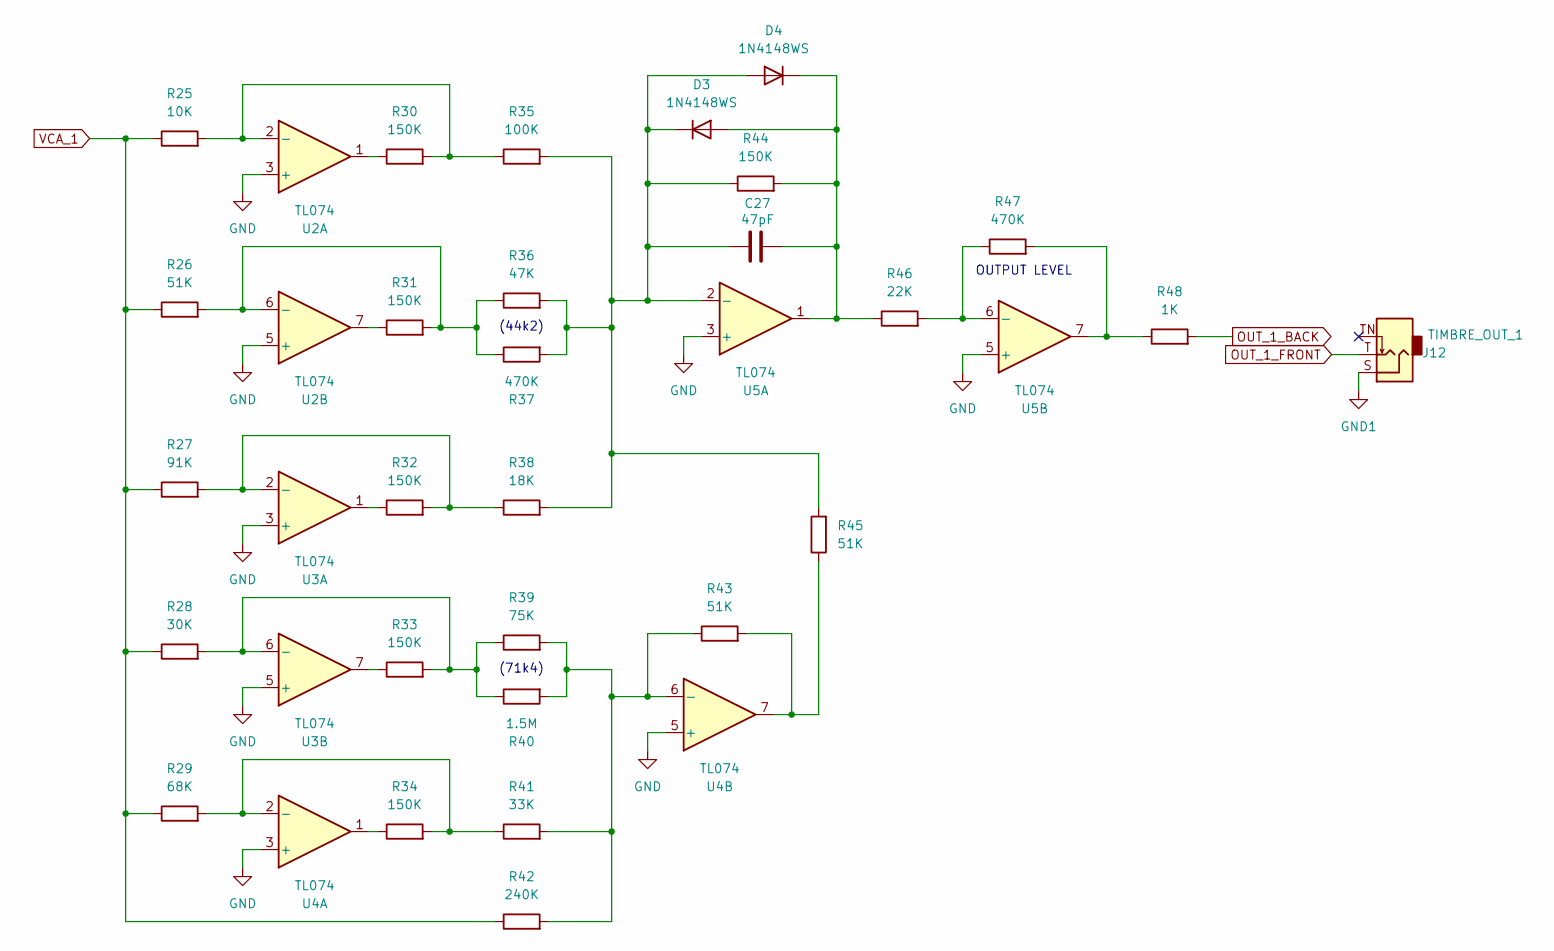
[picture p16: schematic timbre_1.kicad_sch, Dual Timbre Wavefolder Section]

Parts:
C27: 47pF; C_0402_1005Metric; LCSC C1567
D3, D4: 1N4148WS; D_SOD-323; LCSC C2128
J12: TIMBRE_OUT_1; AudioJack_PJ301M-12
R25: 10K; R_0402_1005Metric; LCSC C25744
R26, R43, R45: 51K; R_0402_1005Metric; LCSC C25794
R27: 91K; R_0603_1608Metric; LCSC C23265
R28: 30K; R_0603_1608Metric; LCSC C22984
R29: 68K; R_0402_1005Metric; LCSC C36871
R30, R31, R32, R33, R34, R44: 150K; R_0402_1005Metric; LCSC C25755
R35: 100K; R_0402_1005Metric; LCSC C25741
R36: 47K; R_0402_1005Metric; LCSC C25792
R37: 470K; R_0402_1005Metric; LCSC C25790
R38: 18K; R_0402_1005Metric; LCSC C25762
R39: 75K; R_0402_1005Metric; LCSC C25798
R40: 1.5M; R_0603_1608Metric; LCSC C4172
R41: 33K; R_0402_1005Metric; LCSC C25779
R42: 240K; R_0603_1608Metric; LCSC C4197
R46: 22K; R_0603_1608Metric_Pad0.98x0.95mm_HandSolder; LCSC C31850
R47: 470K; R_0603_1608Metric_Pad0.98x0.95mm_HandSolder; LCSC C23178
R48: 1K; R_0402_1005Metric; LCSC C11702
U2, U3, U4, U5: TL074; SOIC-14_3.9x8.7mm_P1.27mm; LCSC C6963

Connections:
GND: U2.3 (+), U2.5 (+), U3.3 (+), U3.5 (+), U4.3 (+), U4.5 (+), U5.3 (+), U5.5 (+); also elsewhere on the board
GND1: J12.S; also elsewhere on the board
unnamed: C27.2, D3.2 (A), D4.1 (K), R44.2, R46.1, U5.1
unnamed: C27.1, D3.1 (K), D4.2 (A), R35.2, R36.2, R37.2, R38.2, R44.1, R45.2, U5.2 (-)
unnamed: R30.1, U2.1
unnamed: R31.1, U2.7
unnamed: R32.1, U3.1
unnamed: R33.1, U3.7
unnamed: R34.1, U4.1
unnamed: R43.2, R45.1, U4.7
unnamed: R47.2, R48.1, U5.7
unnamed: R25.2, R30.2, R35.1, U2.2 (-)
unnamed: R26.2, R31.2, R36.1, R37.1, U2.6 (-)
unnamed: R27.2, R32.2, R38.1, U3.2 (-)
unnamed: R28.2, R33.2, R39.1, R40.1, U3.6 (-)
unnamed: R29.2, R34.2, R41.1, U4.2 (-)
unnamed: R39.2, R40.2, R41.2, R42.2, R43.1, U4.6 (-)
unnamed: R46.2, R47.1, U5.6 (-)
OUT_1_BACK: R48.2; also elsewhere on the board
OUT_1_FRONT: J12.T; also elsewhere on the board
VCA_1: R25.1, R26.1, R27.1, R28.1, R29.1, R42.1; also elsewhere on the board

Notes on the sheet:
(71k4)
(44k2)
OUTPUT LEVEL

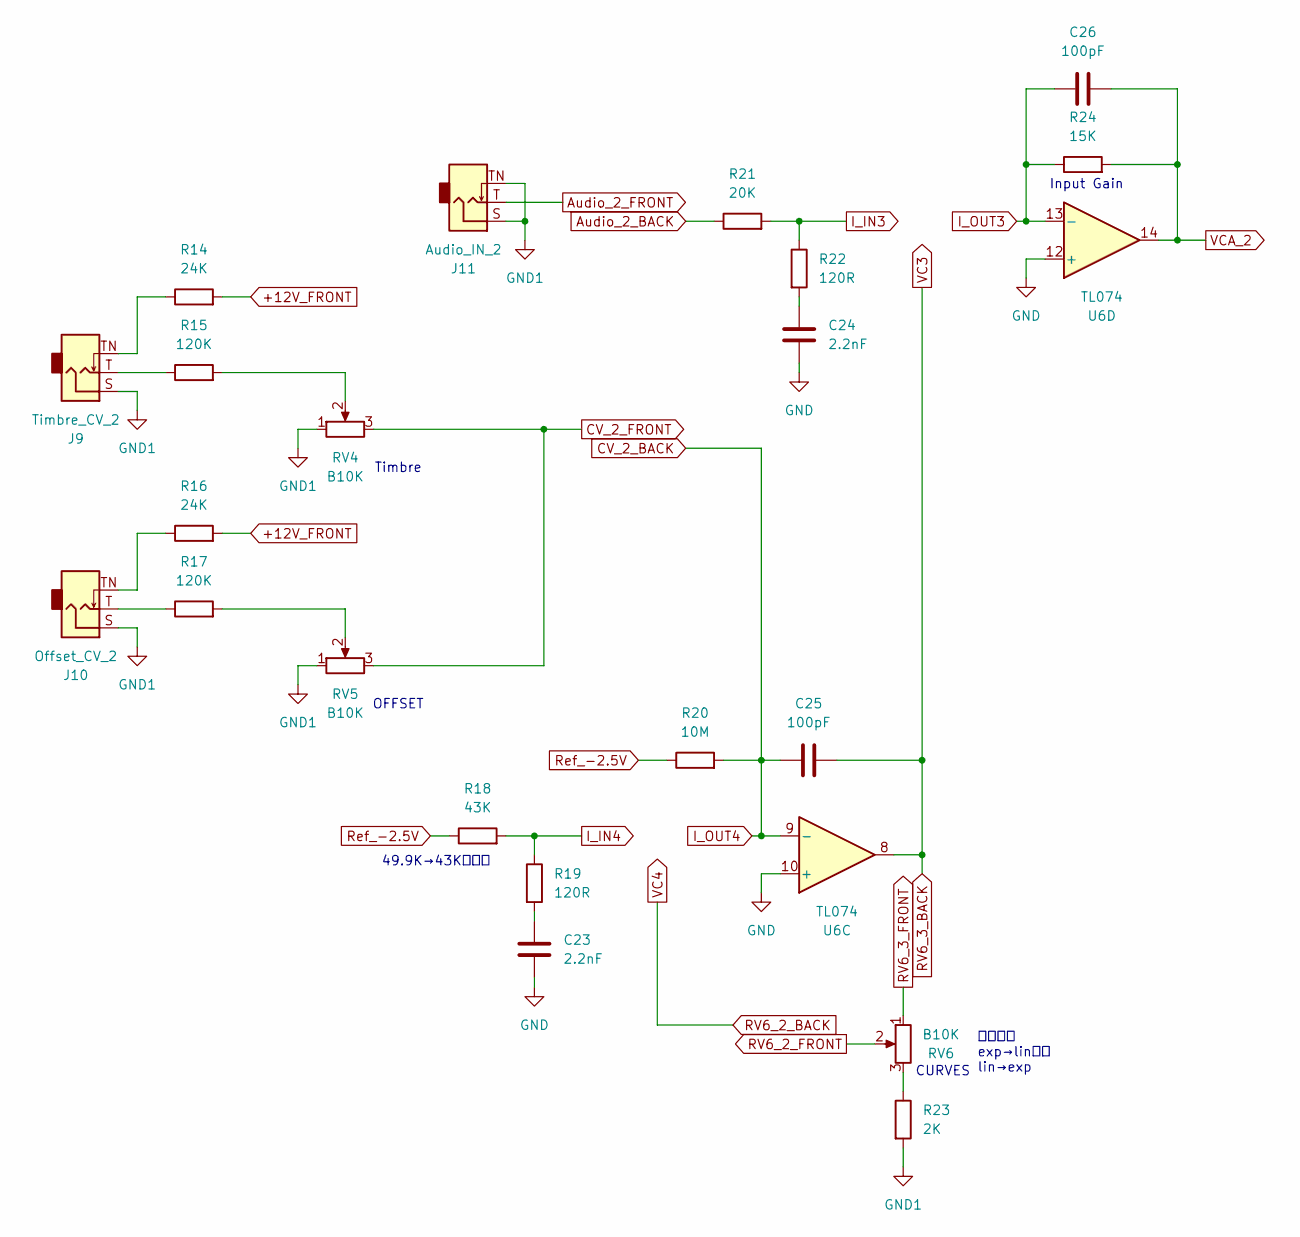
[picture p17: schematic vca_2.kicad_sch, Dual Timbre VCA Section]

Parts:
C23, C24: 2.2nF; R_0805_2012Metric; LCSC C28260
C25, C26: 100pF; C_0402_1005Metric; LCSC C1546
J9: Timbre_CV_2; AudioJack_PJ301M-12
J10: Offset_CV_2; AudioJack_PJ301M-12
J11: Audio_IN_2; AudioJack_PJ301M-12
R14, R16: 24K; R_0603_1608Metric_Pad0.98x0.95mm_HandSolder; LCSC C23352
R15, R17: 120K; R_0603_1608Metric_Pad0.98x0.95mm_HandSolder; LCSC C25808
R18: 43K; R_0603_1608Metric_Pad0.98x0.95mm_HandSolder; LCSC C23172
R19, R22: 120R; R_0402_1005Metric; LCSC C25079
R20: 10M; R_0402_1005Metric; LCSC C26082
R21: 20K; R_0402_1005Metric; LCSC C25765
R23: 2K; R_0603_1608Metric_Pad0.98x0.95mm_HandSolder; LCSC C22975
R24: 15K; R_0603_1608Metric_Pad0.98x0.95mm_HandSolder; LCSC C22809
RV4, RV5, RV6: B10K; Potentiometer_RV09
U6: TL074; SOIC-14_3.9x8.7mm_P1.27mm; LCSC C6963

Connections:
+12V_FRONT: R14.2, R16.2; also elsewhere on the board
Audio_2_BACK: R21.1; also elsewhere on the board
Audio_2_FRONT: J11.T; also elsewhere on the board
CV_2_BACK: C25.1, R20.2, U6.9 (-); also elsewhere on the board
CV_2_FRONT: RV4.3, RV5.3; also elsewhere on the board
GND: C23.2, C24.2, U6.10 (+), U6.12 (+); also elsewhere on the board
GND1: J9.S, J10.S, J11.S, J11.TN, R23.2, RV4.1, RV5.1; also elsewhere on the board
I_IN3: R21.2, R22.1; also elsewhere on the board
I_IN4: R18.2, R19.1; also elsewhere on the board
I_OUT3: C26.1, R24.1, U6.13 (-); also elsewhere on the board
unnamed: C23.1, R19.2
unnamed: C24.1, R22.2
unnamed: J9.T, R15.1
unnamed: J9.TN, R14.1
unnamed: J10.T, R17.1
unnamed: J10.TN, R16.1
unnamed: R15.2, RV4.2
unnamed: R17.2, RV5.2
unnamed: R23.1, RV6.3
RV6_2_FRONT: RV6.2; also elsewhere on the board
RV6_3_BACK: C25.2, U6.8; also elsewhere on the board
RV6_3_FRONT: RV6.1; also elsewhere on the board
Ref_-2.5V: R18.1, R20.1; also elsewhere on the board
VCA_2: C26.2, R24.2, U6.14; also elsewhere on the board

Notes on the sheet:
向き変更 exp→linから lin→exp
Timbre
OFFSET
CURVES
Input Gain
49.9K→43Kに変更

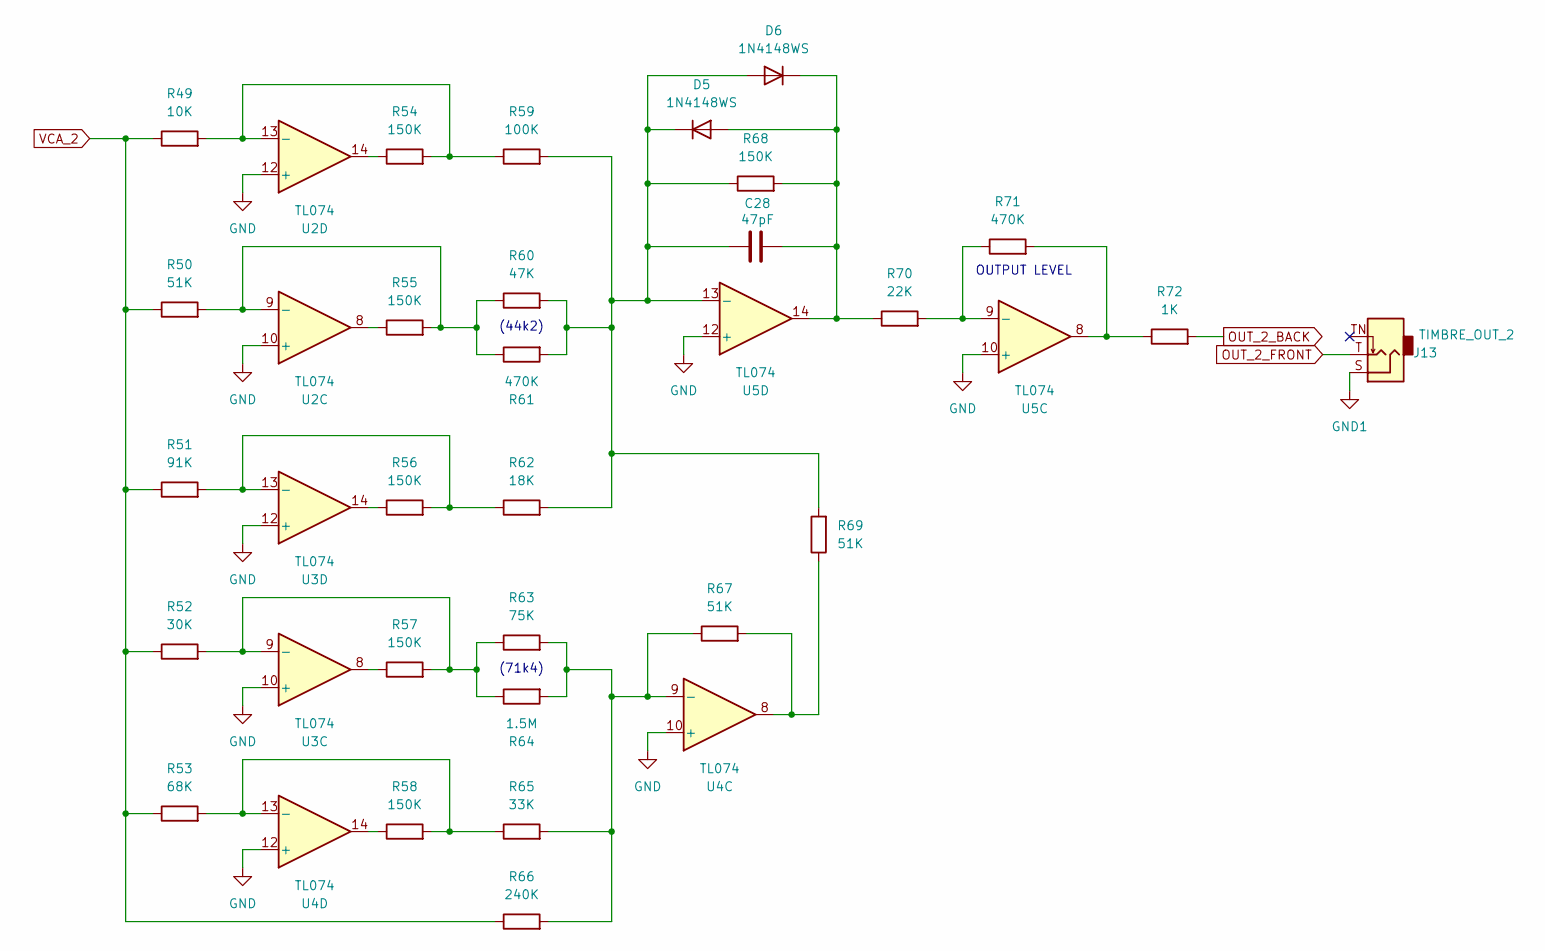
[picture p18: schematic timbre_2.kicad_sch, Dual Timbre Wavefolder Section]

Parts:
C28: 47pF; C_0402_1005Metric; LCSC C1567
D5, D6: 1N4148WS; D_SOD-323; LCSC C2128
J13: TIMBRE_OUT_2; AudioJack_PJ301M-12
R49: 10K; R_0402_1005Metric; LCSC C25744
R50, R67, R69: 51K; R_0402_1005Metric; LCSC C25794
R51: 91K; R_0603_1608Metric; LCSC C23265
R52: 30K; R_0603_1608Metric; LCSC C22984
R53: 68K; R_0402_1005Metric; LCSC C36871
R54, R55, R56, R57, R58, R68: 150K; R_0402_1005Metric; LCSC C25755
R59: 100K; R_0402_1005Metric; LCSC C25741
R60: 47K; R_0402_1005Metric; LCSC C25792
R61: 470K; R_0402_1005Metric; LCSC C25790
R62: 18K; R_0402_1005Metric; LCSC C25762
R63: 75K; R_0402_1005Metric; LCSC C25798
R64: 1.5M; R_0603_1608Metric; LCSC C4172
R65: 33K; R_0402_1005Metric; LCSC C25779
R66: 240K; R_0603_1608Metric; LCSC C4197
R70: 22K; R_0603_1608Metric_Pad0.98x0.95mm_HandSolder; LCSC C31850
R71: 470K; R_0603_1608Metric_Pad0.98x0.95mm_HandSolder; LCSC C23178
R72: 1K; R_0402_1005Metric; LCSC C11702
U2, U3, U4, U5: TL074; SOIC-14_3.9x8.7mm_P1.27mm; LCSC C6963

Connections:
GND: U2.10 (+), U2.12 (+), U3.10 (+), U3.12 (+), U4.10 (+), U4.12 (+), U5.10 (+), U5.12 (+); also elsewhere on the board
GND1: J13.S; also elsewhere on the board
unnamed: C28.2, D5.2 (A), D6.1 (K), R68.2, R70.1, U5.14
unnamed: C28.1, D5.1 (K), D6.2 (A), R59.2, R60.2, R61.2, R62.2, R68.1, R69.2, U5.13 (-)
unnamed: R54.1, U2.14
unnamed: R55.1, U2.8
unnamed: R56.1, U3.14
unnamed: R57.1, U3.8
unnamed: R58.1, U4.14
unnamed: R67.2, R69.1, U4.8
unnamed: R71.2, R72.1, U5.8
unnamed: R50.2, R55.2, R60.1, R61.1, U2.9 (-)
unnamed: R49.2, R54.2, R59.1, U2.13 (-)
unnamed: R52.2, R57.2, R63.1, R64.1, U3.9 (-)
unnamed: R51.2, R56.2, R62.1, U3.13 (-)
unnamed: R63.2, R64.2, R65.2, R66.2, R67.1, U4.9 (-)
unnamed: R53.2, R58.2, R65.1, U4.13 (-)
unnamed: R70.2, R71.1, U5.9 (-)
OUT_2_BACK: R72.2; also elsewhere on the board
OUT_2_FRONT: J13.T; also elsewhere on the board
VCA_2: R49.1, R50.1, R51.1, R52.1, R53.1, R66.1; also elsewhere on the board

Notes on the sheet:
OUTPUT LEVEL
(44k2)
(71k4)

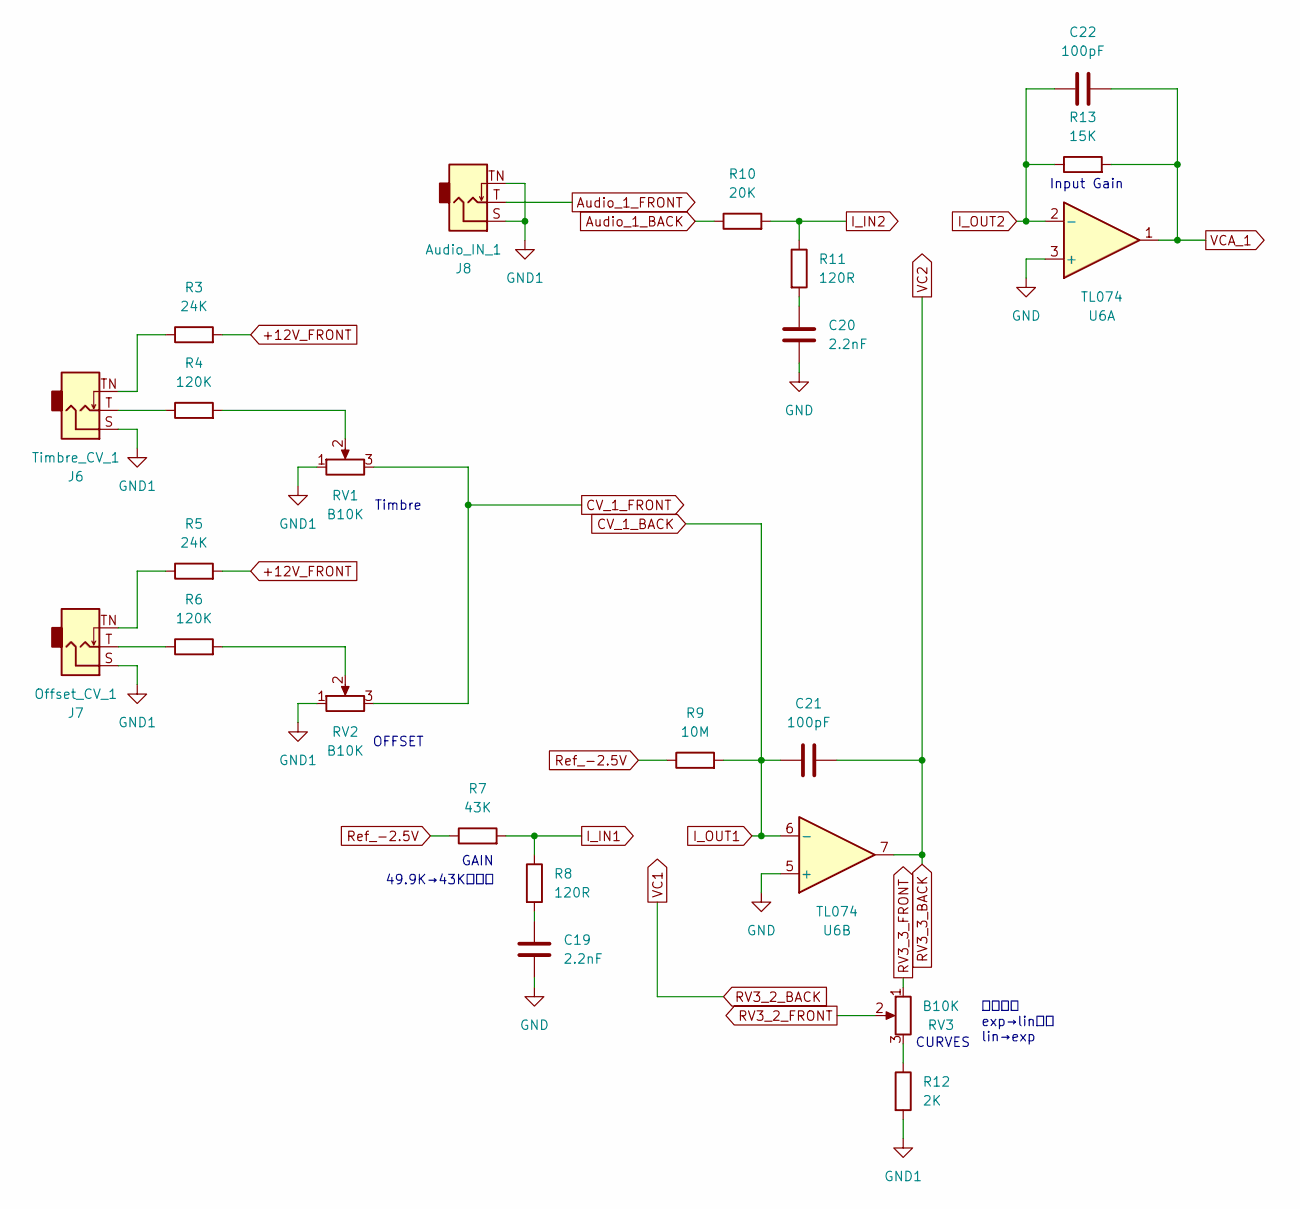
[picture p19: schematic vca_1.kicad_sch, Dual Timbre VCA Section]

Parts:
C19, C20: 2.2nF; R_0805_2012Metric; LCSC C28260
C21, C22: 100pF; C_0402_1005Metric; LCSC C1546
J6: Timbre_CV_1; AudioJack_PJ301M-12
J7: Offset_CV_1; AudioJack_PJ301M-12
J8: Audio_IN_1; AudioJack_PJ301M-12
R3, R5: 24K; R_0603_1608Metric_Pad0.98x0.95mm_HandSolder; LCSC C23352
R4, R6: 120K; R_0603_1608Metric_Pad0.98x0.95mm_HandSolder; LCSC C25808
R7: 43K; R_0603_1608Metric_Pad0.98x0.95mm_HandSolder; LCSC C23172
R8, R11: 120R; R_0402_1005Metric; LCSC C25079
R9: 10M; R_0402_1005Metric; LCSC C26082
R10: 20K; R_0402_1005Metric; LCSC C25765
R12: 2K; R_0603_1608Metric_Pad0.98x0.95mm_HandSolder; LCSC C22975
R13: 15K; R_0603_1608Metric_Pad0.98x0.95mm_HandSolder; LCSC C22809
RV1, RV2, RV3: B10K; Potentiometer_RV09
U6: TL074; SOIC-14_3.9x8.7mm_P1.27mm; LCSC C6963

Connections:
+12V_FRONT: R3.2, R5.2; also elsewhere on the board
Audio_1_BACK: R10.1; also elsewhere on the board
Audio_1_FRONT: J8.T; also elsewhere on the board
CV_1_BACK: C21.1, R9.2, U6.6 (-); also elsewhere on the board
CV_1_FRONT: RV1.3, RV2.3; also elsewhere on the board
GND: C19.2, C20.2, U6.3 (+), U6.5 (+); also elsewhere on the board
GND1: J6.S, J7.S, J8.S, J8.TN, R12.2, RV1.1, RV2.1; also elsewhere on the board
I_IN1: R7.2, R8.1; also elsewhere on the board
I_IN2: R10.2, R11.1; also elsewhere on the board
I_OUT2: C22.1, R13.1, U6.2 (-); also elsewhere on the board
unnamed: C19.1, R8.2
unnamed: C20.1, R11.2
unnamed: J6.T, R4.1
unnamed: J6.TN, R3.1
unnamed: J7.T, R6.1
unnamed: J7.TN, R5.1
unnamed: R4.2, RV1.2
unnamed: R6.2, RV2.2
unnamed: R12.1, RV3.3
RV3_2_FRONT: RV3.2; also elsewhere on the board
RV3_3_BACK: C21.2, U6.7; also elsewhere on the board
RV3_3_FRONT: RV3.1; also elsewhere on the board
Ref_-2.5V: R7.1, R9.1; also elsewhere on the board
VCA_1: C22.2, R13.2, U6.1; also elsewhere on the board

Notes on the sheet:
Timbre
GAIN
向き変更 exp→linから lin→exp
Input Gain
49.9K→43Kに変更
CURVES
OFFSET

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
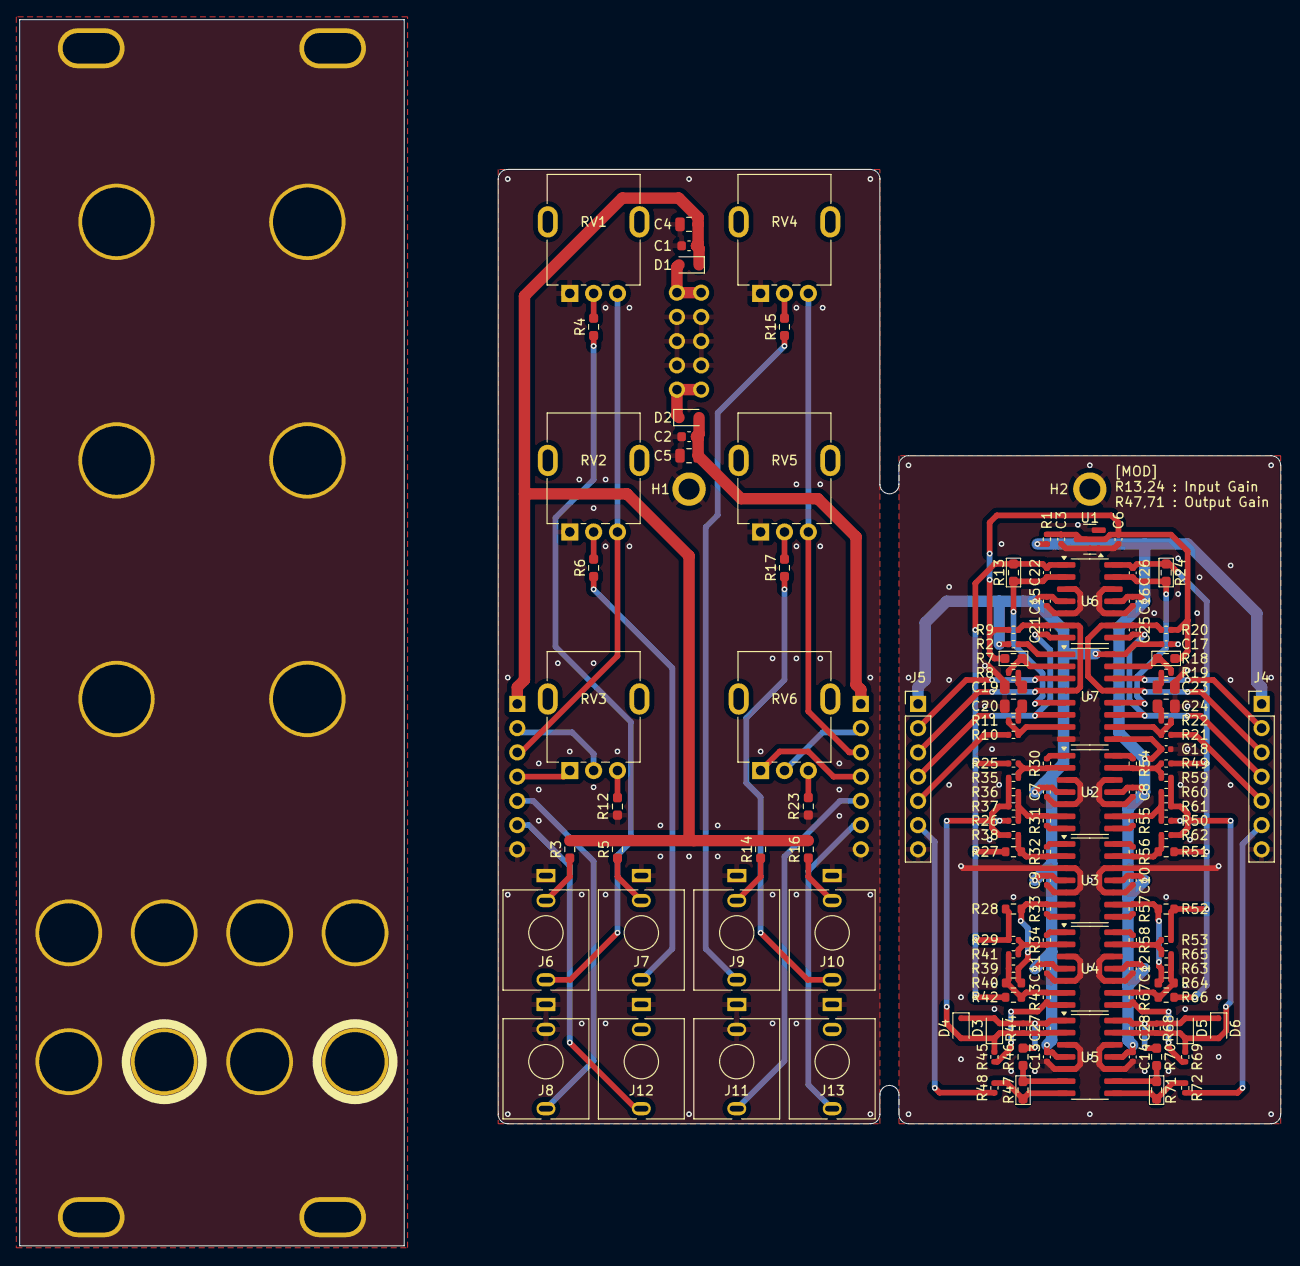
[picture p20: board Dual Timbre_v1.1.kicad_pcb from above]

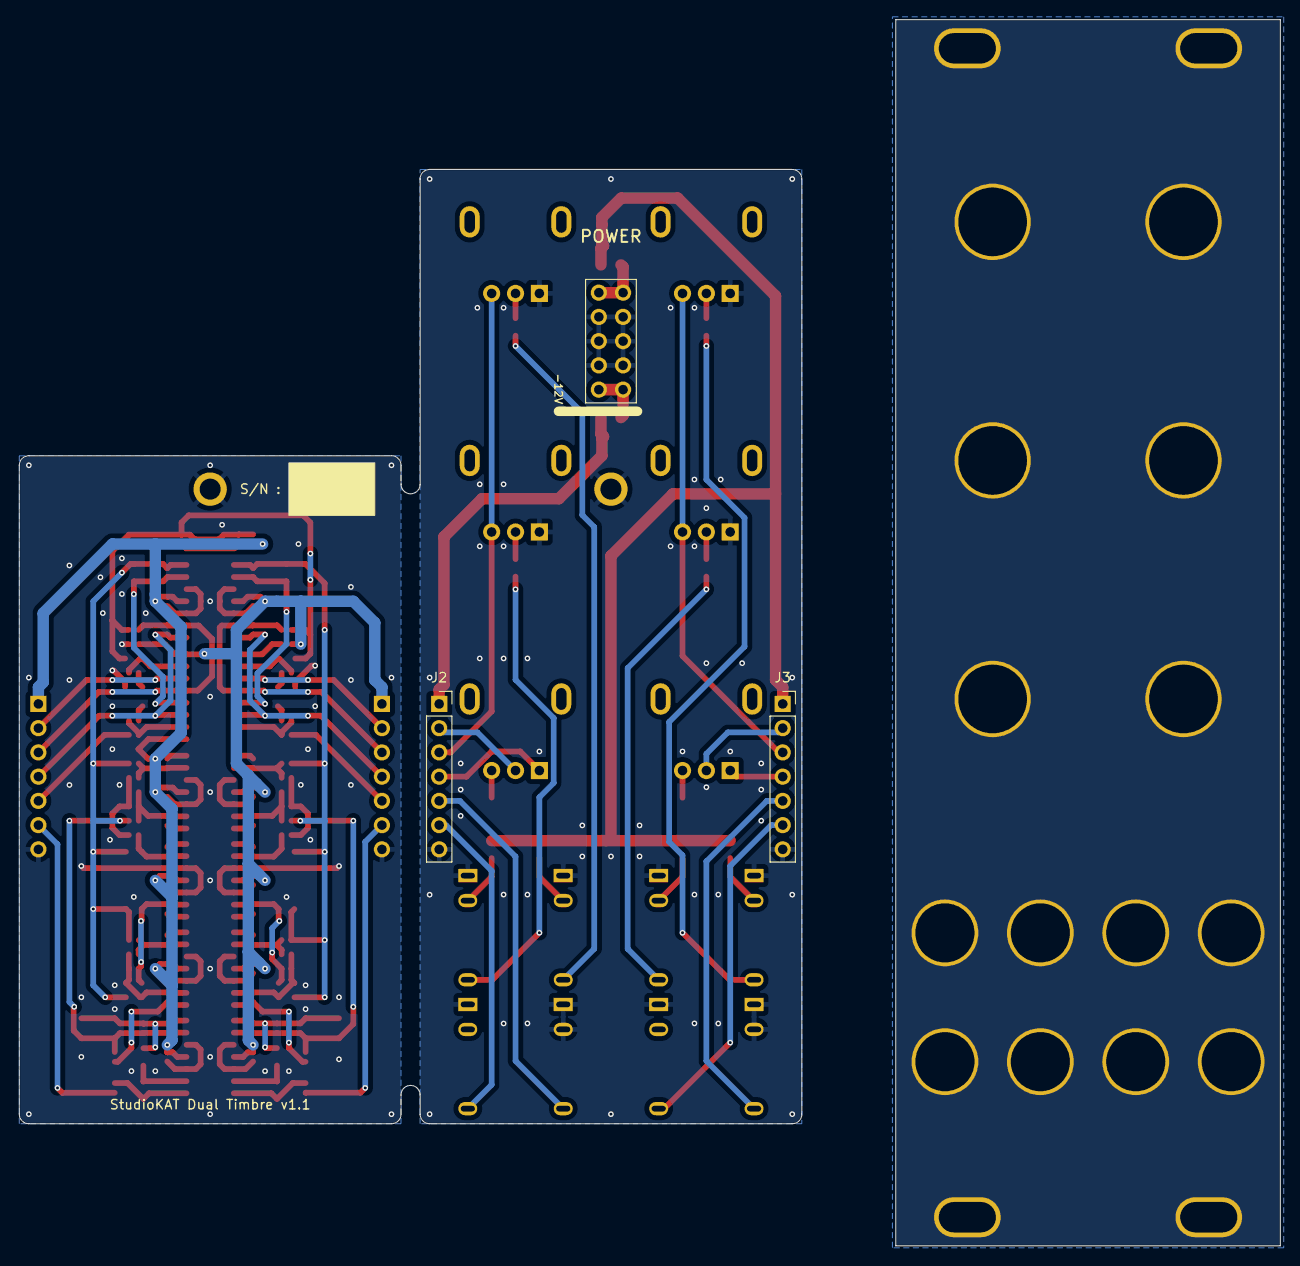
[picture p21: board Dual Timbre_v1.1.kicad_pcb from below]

Board: 2 copper layers, 82.0 x 100.0 mm, 149 parts (3 on the bottom side), 89 nets.

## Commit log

2025-04-30 README改行修正
2025-04-30 マニュアルJP改行修正
2025-05-28 KiCAD、画像追加
    [Dual Timbre_v1.0.kicad_pcb, Dual Timbre_v1.0.kicad_sch, bom.csv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]
2025-05-29 動画追加
2025-06-08 v1.1 Curveの向き変更
    [Dual Timbre_v1.1.kicad_pcb, Dual Timbre_v1.1.kicad_sch, bom.csv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]
